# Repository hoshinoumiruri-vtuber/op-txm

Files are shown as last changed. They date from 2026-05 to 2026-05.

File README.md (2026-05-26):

# op-txm — Transformer-Output Condenser Microphone

Solid-state condenser microphone with transformer-balanced output.

---

## Table of Contents

1. [System Architecture](#1-system-architecture)
2. [Technical Specifications](#2-technical-specifications)
3. [Output Transformer — Neutrik NTE10/3](#3-output-transformer--neutrik-nte103)
4. [Engineering Verification and Simulation Results](#4-engineering-verification-and-simulation-results)
5. [Toolchain](#5-toolchain)
6. [Getting Started](#6-getting-started)
7. [Project Phases](#7-project-phases)
8. [Repository Structure](#8-repository-structure)

---

## 1. System Architecture

```
[XLR Phantom 48V] --> [LR8 Pre-reg 35.2V + Charge Pump] --> [JFET Input Buffer + DC Servo]
                              |                                            |
                        [TPS7A3901 +/-15V]                   [K47/K87 De-emphasis EQ]
                                                                           |
                                                          [NTE10/3 Output Transformer 1:3]
                                                                           |
                                                                    [XLR Balanced Out]
```

| Stage | Description |
|---|---|
| Power | LR8 pre-regulator (48V phantom → 35.2V). Diode charge pump → V_BOOST for JFET drain. TPS7A3901 WSON-12 → ±15V op-amp supply. Total draw 9.1 mA typ (< 10 mA IEC 61938). |
| Input | High-Z JFET buffer (MMBF170LT1G SOT-23) with op-amp DC servo for bias stability. |
| EQ | Active de-emphasis network tuned for K67/K87. Flat (K47) or −6 dB shelf above ~22 kHz (K87) via SJ1 solder bridge. |
| Output | Neutrik NTE10/3, reversed 3:1 connection (op-amp drives 3× winding, XLR from 1× winding): transformer-balanced, galvanic isolation, passive CMRR, Zout ≈ 255 Ω. |

---

## 2. Technical Specifications

| Parameter | Value |
|---|---|
| Supply | +48V phantom power (IEC 61938) |
| Internal rail | 35.2V (LR8 pre-reg) → ±15V (TPS7A3901); V_BOOST charge pump for JFET drain |
| Max current draw | < 10 mA (IEC 61938 phantom limit); typical 9.1 mA |
| Capsule | Takstar K87, 34 mm rim-terminated |
| Capsule compatibility | K47 (flat) and K87/K67 (de-emphasised) via SJ1 solder bridge |
| PCB form factor | 40×100 mm |
| Mounting | 4× M2.2 NPTH, rectangular pattern (30×80 mm) |
| Assembly | SMD for all active/passive components; through-hole for capsule leads and NTE10/3 transformer leads |
| De-emphasis network | R_shelf = 47 kΩ, C_deemph = 150 pF — −6 dB shelf above ~22 kHz |
| Output stage | Neutrik NTE10/3, reversed 3:1 connection (−9.5 dB, Zout ≈ 255 Ω) — standard Neumann/AKG practice |
| EQ op-amp | OPA1642AIDR (dual JFET-input, GBW=11 MHz, EIN=5.1 nV/√Hz) |
| Output balance | Transformer CMRR (passive) — no active output op-amp required |
| Output impedance | ~540 Ω referred to secondary (JFET 60Ω × n²=9) |

---

## 3. Output Transformer — Neutrik NTE10/3

### Confirmed specifications

| Parameter | Value | Source |
|---|---|---|
| Turns ratio | 1:3:10 (two secondary taps) | Neutrik datasheet |
| Selected tap | 1:3 (secondary = 1.8 kΩ) | Design choice |
| Primary impedance | 200 Ω | Neutrik / Farnell |
| Secondary impedance (1:3 tap) | 1.8 kΩ | Neutrik / Farnell |
| Secondary impedance (1:10 tap) | 20 kΩ | Neutrik / Farnell |
| Frequency response | 40 Hz – 20 kHz ±0.5 dB | Distributor spec |
| Solderability | IEC 68-2-20 compliant | Neutrik datasheet |
| Primary inductance | ~80 H (community measurement) | GroupDIY forum |
| Primary DCR (1× winding) | 105 Ω ±5% | Neutrik datasheet |
| Secondary DCR (3× winding) | 1.25 kΩ ±5% | Neutrik datasheet |
| Leakage inductance | **TBD — measure at bench** | — |

> After bench measurement, update DCR and leakage inductance values in `sim/tx_output.py` and `sim/signal_chain.py`.

### Wiring / connection — reversed 3:1 (Neumann/AKG standard)

Op-amp EQ output drives the **3× (secondary) winding**; XLR balanced output comes from the **1× (primary) winding**.

```
NTE10/3 lead colour (typical) — reversed 3:1 connection:
  3× winding (driven by EQ op-amp):
    Blue  → EQ op-amp output (hot drive)
    White → Signal GND (3× winding return)
    Yellow→ Centre tap → signal GND (if used; tie to GND or leave floating)
  1× winding (XLR balanced output):
    Red   → XLR pin 2 (hot)
    Black → XLR pin 3 (cold)
```

> **Verify lead colours against the physical unit** — Neutrik wire colours are not always consistent across production batches. Use an LCR meter to confirm winding connections before soldering.

### PCB mounting

The NTE10/3 is an encapsulated off-board transformer connected via its free wires. It is **not** mounted on the PCB directly.

- Solder the five leads to through-hole pads on the PCB (1.0 mm drill, 2.5 mm annular ring recommended)
- Secure the transformer body inside the mic capsule body with two cable ties through 2.5 mm NPTH slots at the PCB edge (or adhesive mount to the capsule basket)
- Allow enough wire slack for the transformer to not stress the PCB pads

---

## 4. Engineering Verification and Simulation Results

All simulations run analytically (Python) with ngspice batch mode for transient verification.

### 4.1 Power Stage

72V boost stage (Cockcroft-Walton charge pump), LR8 pre-regulator, TPS7A39 ±15V.

| Parameter | Value | Status |
|---|---|---|
| 72V rail ripple (after LC filter) | 0.088 µV p-p | PASS |
| LR8 junction temperature | 63.0 °C (45 °C ambient) | PASS |
| TPS7A39 junction temperature | 48.7 °C (45 °C ambient) | PASS |
| Phantom current draw | 9.09 mA typ / 10.97 mA max | PASS typ (< 10 mA IEC 61938) |

### 4.2 JFET Buffer + DC Servo

MMBF170 JFET, OPA2134 servo, Vdrain locked to 36 V ±1 V across 0–50 °C.

| Parameter | Value | Status |
|---|---|---|
| gm at operating point | 16.18 mA/V | — |
| Gain drift over temperature | 0.0 dB | PASS |
| Servo phase margin | 90° | PASS |
| EIN @ 1 kHz | 13.01 nV/√Hz | — |

### 4.3 K47/K87 De-emphasis EQ

| Frequency | K47 gain | K87 gain |
|---|---|---|
| 20 Hz | 0.00 dB | 0.00 dB |
| 1 kHz | 0.00 dB | −0.03 dB |
| 10 kHz | 0.00 dB | −1.74 dB |
| 20 kHz | 0.00 dB | −3.65 dB |

Phase margin ≥ 90° across all EQ states.

### 4.4 Full Signal Chain (sim/signal_chain.py) — ngspice PASS

K47/K87 modes, JFET → OPA1642 EQ → NTE10/3 → 600 Ω balanced load.

| Parameter | Value | Notes |
|---|---|---|
| Differential gain @ 1 kHz (K47) | +16.0 dB | Balanced output, reversed 3:1 TX |
| Differential gain @ 20 kHz (K47) | +16.0 dB | Flat within 0.1 dB |
| K87 shelf @ 20 kHz | −3.7 dB | Expected — shelf corner is 22.6 kHz |
| K87 shelf @ 100 kHz | −5.9 dB | PASS (target −6 dB ±1.5 dB) |
| Bandwidth LF −3 dB (K47) | 10.2 Hz | Sub-Hz with servo-locked Q-point |
| Bandwidth HF −3 dB (K47) | > 100 kHz | Well above audio band |
| Phase @ 1 kHz (K47) | +0.5° | — |
| Transformer connection | Reversed 3:1 (−9.5 dB) | Op-amp drives 3× winding; Zout ≈ 255 Ω at XLR |
| Transformer LF −3 dB | ~0.30 Hz | Estimated (Ldriven=720 H, DCR_sec=1.25 kΩ) |
| Transformer HF −3 dB | ~415 kHz analytical | Estimated (Lleak TBD at bench); reversed 3:1 extends HF vs forward |

> Transformer DCR and leakage inductance are estimated. Update `sim/tx_output.py` and `sim/signal_chain.py` after bench measurement.

---

## 5. Toolchain

| Tool | Purpose | Version |
|---|---|---|
| Python | Primary language | 3.12+ |
| uv | Package and environment management | 0.11.8+ |
| ngspice | SPICE simulation engine | 46 |
| PySpice | Python wrapper for ngspice | 1.5 |
| KiCad | PCB design (code-driven layout via kiutils) | 10.0.3+ |
| numpy / scipy | Numerical analysis | 2.4 / 1.17 |
| matplotlib | Plotting | 3.10 |

> **PCB layout is code-driven** — kiutils scripts generate the KiCad PCB file. See `docs/pcb_routing_knowhow.md` for routing rules and constraints.

> **ngspice -b batch mode** — do not use PySpice's `NgSpiceShared` API (unreliable with ngspice 42+).

---

## 6. Getting Started

### Prerequisites

```bash
# Arch Linux
sudo pacman -S ngspice kicad

# Ubuntu / Debian
sudo apt install ngspice kicad
```

### Python Environment

```bash
uv sync
```

### Running Simulations

```bash
source .venv/bin/activate

# Power stage
python sim/boost_72v.py

# JFET buffer + DC servo
python sim/dc_servo.py

# K47/K87 de-emphasis EQ
python sim/dual_capsule_eq.py

# Transformer output stage (update DCR/Lleak values first)
python sim/tx_output.py

# Generate all plots
python sim/generate_plots.py
```

### Generating PCB Files

The KiCad project is fully code-driven. Two scripts must be run before opening KiCad:

```bash
# 1. Generate the KiCad project file (net classes, DRC rules, HV net assignments)
python pcb/project.py        # → pcb/op-txm.kicad_pro

# 2. Generate the board layout (outline, component placement, GND fill zone)
python pcb/layout.py         # → pcb/op-txm.kicad_pcb + pcb/op_txm_layout.png
```

Open the project in KiCad 10:

```bash
kicad pcb/op-txm.kicad_pro
```

> Always open via `.kicad_pro`, not `.kicad_pcb` directly — the project file carries the HV net class assignments and DRC rules. If you regenerate either file, re-open the project in KiCad (the board file is reloaded automatically).

After opening in KiCad:
1. **Fill All Zones** (`B` key) — floods the B.Cu GND plane
2. **Run DRC** — verify zero clearance violations, zero unrouted nets flagged as errors
3. **Route remaining nets** interactively (capsule signal, HV supply, EQ → transformer)
4. **Export Gerbers** — `File → Fabrication Outputs → Gerbers`, output to `gerbers/`

---

## 7. Project Phases

### Phase 1: Simulation — COMPLETE

- [x] Power stage simulation (boost_72v.py) — 0.088 µV ripple PASS
- [x] Phantom power budget (phantom_budget.py) — 9.09 mA typ PASS (< 10 mA IEC 61938)
- [x] JFET buffer + DC servo simulation (dc_servo.py)
- [x] K47/K87 EQ simulation (dual_capsule_eq.py)
- [x] Transformer output stage analytical model (tx_output.py) — LF=0.30 Hz, HF=415 kHz
- [x] Full signal-chain AC sweep (signal_chain.py) — 16.0 dB diff gain, K87 shelf −5.9 dB @ 100 kHz PASS
- [ ] Measure NTE10/3 DCR and leakage inductance (bench LCR meter) — deferred to Phase 4
- [ ] Update tx_output.py and signal_chain.py with measured values — deferred to Phase 4

### Phase 2: PCB Layout (code-driven via kiutils) — IN PROGRESS

- [x] Add kiutils to pyproject.toml, scaffold pcb/layout.py
- [x] Generate .kicad_pro (pcb/project.py) with HV net class and DRC rules
- [x] Define board outline: 35×85 mm, 4× M2.2 NPTH (30×80 mm pattern) — pcb/outline.py
- [x] Place components via script: power stage, JFET buffer, EQ, transformer TH pads
- [x] Define HV keepout zone (outline.py), B.Cu GND plane (layout.py)
- [x] Add NPTH zip-tie slots (2.5 mm) at PCB edge for transformer retention
- [x] Transformer bobbin cutout (10×8 mm interior rectangle, Edge.Cuts)
- [ ] Route critical nets (capsule signal, HV supply, EQ output) — interactive in KiCad
- [ ] DRC — zero clearance violations
- [ ] Fill All Zones, export Gerbers

### Phase 3: BOM + Procurement

- [x] Generate BOM (bom/generate_bom.py) — 31 line items, 35 SMD placements
- [x] DFM review (bom/txm_bom_dfm.txt) — board parameters, TH hand-solder notes
- [ ] Order NTE10/3 (check stock: Farnell, Mouser)
- [ ] Order long-lead parts: IXYS LR8, TPS7A3901

### Phase 4: Bench Validation (hardware)

- [ ] Power-on: verify 35.2V LR8 rail, ±15V, V_BOOST
- [ ] DC servo: check Vdrain = 36V ±1V across 0–50°C
- [ ] Noise floor A-weighted (target < 14 dB-A)
- [ ] Frequency response 20Hz–20kHz (±1 dB)
- [ ] Output CMRR via transformer (target > 60 dB at 1 kHz)
- [ ] Phantom current draw (target < 7 mA)
- [ ] Acoustic evaluation

---

## 8. Repository Structure

```
op-txm/
├── pyproject.toml
├── README.md
├── sim/
│   ├── boost_72v.py          # Power stage simulation
│   ├── dc_servo.py           # JFET DC servo simulation
│   ├── dual_capsule_eq.py    # K47/K87 EQ simulation
│   ├── tx_output.py          # NTE10/3 transformer output stage
│   ├── generate_plots.py     # Batch plot generator
│   └── models/               # Ngspice device models
├── bom/
│   └── generate_bom.py       # BOM generator
├── pcb/                      # KiCad project files (code-driven layout)
│   └── notes.md              # PCB constraints and layout notes
├── docs/
│   └── pcb_routing_knowhow.md # Routing rules and constraints
└── assets/
    └── sim_results/           # Generated plots
```

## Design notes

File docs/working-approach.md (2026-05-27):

# Working Approach — op-txm PCB Development

## Core rule

**Write code → run → fix errors → commit. No pre-solving geometry in prose.**  
If the geometry is unclear, write the attempt, see what DRC says, iterate.

---

## Iteration loop

```
edit layout.py
→ uv run python pcb/layout.py
→ open in KiCad → Inspect → Design Rules Checker → save report to pcb/DRC.rpt
→ read DRC.rpt, pick next root-cause short
→ repeat
```

DRC.rpt is gitignored (generated artefact). The .kicad_pcb is also gitignored — it is always regenerated from layout.py.

---

## Batching

Fix **one root-cause short per commit**. A root-cause short typically clears 5–20 downstream
solder_mask_bridge / tracks_crossing entries. Do not attempt multiple root causes in one pass —
the interactions are hard to predict and error output becomes unreadable.

After each fix commit, re-run DRC and update `docs/drc-fix-plan.md` with new violation count.

---

## DRC priority order

1. **shorting_items** — hard shorts between different nets (circuit-breaking)
2. **tracks_crossing / clearance** — routing overlaps, HV clearance violations
3. **unconnected_items** — floating pads
4. **Warnings** (text_height, silk_overlap, lib_footprint, via_dangling) — fix last or waive

**Always waive**: WSON-12 (U3 TPS7A3901) adjacent-pad clearances — structural, 0.5mm pitch.

---

## Routing conventions

| Net type | Width | Layer |
|---|---|---|
| PHANTOM, V_BOOST, BP_CAPSULE | 0.40 mm | F.Cu |
| P15V, N15V, P48V_LDO, GND | 0.30 mm | F.Cu |
| SIG_EQ, SRV_OUT, SRV_INT, VSOURCE | 0.20 mm | F.Cu |
| VGATE, FP_CAPSULE | 0.15 mm | F.Cu |
| Via | Ø0.60 mm / drill 0.30 mm | F.Cu–B.Cu |

HV net (PHANTOM, V_BOOST, BP_CAPSULE) clearance: **0.5 mm** to any other net (enforced via op-txm.kicad_dru).

---

## Pad position reference (absolute canvas coords)

All components are placed relative to board centre (100, 100).

### U1 OPA1642 SOIC-8 at (100, 81), pitch 1.27 mm
Left pads X=97.3: pin1=SIG_EQ(79.095), pin2=SIG_EQ(80.365), pin3=GND(81.635), pin4=N15V(82.905)  
Right pads X=102.7: pin5=GND(82.905), pin6=SRV_INT(81.635), pin7=SRV_OUT(80.365), pin8=P15V(79.095)  
Pad half-width = 0.775 mm → right-pad right edge = **103.475 mm** (safe-zone boundary for P15V trunk)

### U3 TPS7A3901 WSON-12 at (100, 110), pitch 0.5 mm
Left pads X=98.35: p1=P48V_LDO(108.75), p2=P48V_LDO(109.25), p3=TPS_FB_NEG(109.75), p4=N15V(110.25), p5=TPS_FB_NEG(110.75), p6=P48V_LDO(111.25)  
Right pads X=101.65: p7=P48V_LDO(111.25), p8=TPS_FB_POS(110.75), p9=P15V(110.25), p10=TPS_FB_POS(109.75), p11=P48V_LDO(109.25), p12=P48V_LDO(108.75)  
EP (GND) centre (100, 110), 1.7×1.7 mm

### U2 LR8 SOT-89 at (91, 110.5)
pin1=LR8_ADJ(89.5, 112.5), pin2=P48V_LDO(91.0, 112.5), pin3=PHANTOM(92.5, 112.5), tab=PHANTOM(91.0, 108.5)

---

## DRC fix batches (see drc-fix-plan.md for detail)

| Batch | Root cause | Status |
|---|---|---|
| B1 | V_BOOST trunk: F.Cu jog → via at (108.5,63.7) → B.Cu X=113.1 → via at (113.1,116) → F.Cu | DONE — 273→263 |
| B2 | Move P15V trunk X=103.5 → X=104.5 (clears U1 right pads + N15V) | TODO |
| B3 | Reroute N15V around P48V_LDO stubs (not through Y=108.5) | TODO |
| B4 | Jog PHANTOM trunk west of LR8_ADJ pad at (89.5, 112.5) | TODO |
| B5 | Reroute P48V_LDO from U2 around SIG_EQ trunk at X=93.5 | TODO |
| B6 | Fix XLR_COLD jog X=110.7 → X=110.3 (clears XLR2 HOT pad) | TODO |
| B7 | Move GND via (88,121) — SIG_EQ trunk endpoint; fix SIG_EQ→TX_DRV_HOT net | TODO |
| B8 | Connect TPS_FB_POS/NEG to U3 pins 8,10 and 3,5 | TODO |
| B9 | Connect GND islands (decoupling cap GND pads → stitching vias) | TODO |

---

## File map

```
pcb/
  layout.py          — all component placement + routing (edit this)
  outline.py         — board outline, mounting holes, TX cutout (rarely edit)
  op-txm.kicad_dru   — custom HV clearance rules
  op-txm.kicad_pcb   — generated (gitignored, regenerate with layout.py)
  DRC.rpt            — generated (gitignored, save from KiCad DRC dialog)

docs/
  drc-fix-plan.md    — root-cause analysis + batch fix plan
  working-approach.md — this file
  pcb_routing_knowhow.md — general routing rules (ported from OCM)
```

---

## Git commit hygiene

- One commit per completed batch
- Commit message format: `pcb: fix <short description> (DRC Bn)`
- Never commit .kicad_pcb or DRC.rpt (gitignored)
- After all DRC errors resolved → final commit: `pcb: DRC clean, ready for Gerber export`

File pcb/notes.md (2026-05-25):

# PCB Design Notes — op-txm

## Board outline (same as OCM body)

- Size: 40×100 mm
- Mounting: 4× M2.2 NPTH at corners of 30×80 mm rectangular pattern
- Form factor: cylindrical microphone body, same as OCM

## Pad rules

- **SMD pads only** for resistors, capacitors, ICs, diodes — standard reflow assembly
- **Through-hole** for:
  - Capsule backplate and diaphragm leads (2 holes)
  - NTE10/3 transformer leads (5 holes — primary ×2, secondary ×3 or per winding count)
  - XLR wire solder points (3 holes — pin 1/2/3)

## Through-hole specifications

| Connection | Drill | Annular ring | Notes |
|---|---|---|---|
| Capsule leads | 0.8 mm | 1.5 mm | Fine wire; keep away from HV copper |
| Transformer leads (NTE10/3) | 1.0 mm | 2.5 mm | Hand-solder after reflow |
| XLR cable wires | 1.0 mm | 2.0 mm | At PCB tail end |

## HV keepout zone

- PHANTOM (48V) and V_BOOST (72V) nets require 0.5 mm clearance to all other copper
- Define a KiCad keepout zone in the bottom ~30 mm of the board (power zone)
- Capsule bias net (BP_CAPSULE, ~48V) — keep isolated from signal traces; minimum 0.5 mm clearance

## NTE10/3 transformer lead pads

The NTE10/3 has **5 free-wire leads** in the 1:3 configuration (2 primary + 2 for 1:3 secondary tap + 1 centre tap).
All leads get through-hole pads. Connection is **reversed 3:1** — op-amp drives the 3× secondary, XLR from 1× primary.

| Pad label | Drill | Function |
|---|---|---|
| TX_S3_HOT, TX_S3_RTN | 1.0 mm | 3× secondary — **driven by op-amp EQ output** (Blue / White leads) |
| TX_S3_CT | 1.0 mm | 3× secondary centre tap → signal GND (Yellow lead, tie to GND) |
| TX_P1, TX_P2 | 1.0 mm | 1× primary — **XLR pin 2 (hot) and XLR pin 3 (cold)** (Red / Black leads) |

The 1:10 secondary dummy pads serve two purposes:
1. Mechanical anchor — the leads are still soldered for strain relief
2. Future option — can be used if a different gain structure is needed

Mark the dummy pads in silkscreen: "TX 1:10 — NC" (no connect).
Do NOT leave 1:10 secondary leads hanging in air — solder them to the dummy pads.

Add 2× NPTH slots (2.5 mm) at PCB edge for cable-tie retention of the transformer body.

## NTE10/3 mounting

- Transformer body sits **off the PCB** — inside the mic basket or body, secured with cable ties
- Two 2.5 mm NPTH slots at PCB edge (or holes at 15 mm spacing) for cable tie retention
- Lead wire length: allow 40–60 mm of free wire from transformer body to PCB solder pads
- Solder pads for transformer leads: through-hole, 1.0 mm drill, placed near the PCB tail (XLR end)

## Capsule connection

- Two through-holes for capsule leads (backplate and diaphragm)
- Place at the PCB head (capsule end, opposite XLR)
- Keep VGATE trace (hi-Z, 1 GΩ gate bias) away from all other copper — 0.5 mm isolation clearance
- VGATE trace width: 0.15 mm, no copper pour closer than 0.5 mm on either layer

## Signal chain reference (left to right on 100 mm axis)

```
[Capsule TH pads] -- [JFET + Servo zone] -- [EQ zone] -- [Power zone] -- [Transformer TH pads + XLR TH pads]
   Y=0 (head end)                                                              Y=100 mm (tail end)
```

## Ground plane

- Solid B.Cu GND fill, 0.3 mm clearance, 0.5 mm thermal relief on SMD pads
- GND stitching: ≥1 via per zone, Ø0.3 mm drill / 0.6 mm Cu
- TPS7A39 exposed pad: 4 thermal vias (2×2, Ø0.25 mm) under EP

## Trace widths

| Net | Width |
|---|---|
| PHANTOM, V_BOOST (HV) | 0.40 mm |
| Power rails (P15V, N15V, P48V_LDO) | 0.30 mm |
| Signal | 0.15–0.20 mm |
| VGATE, FP_CAPSULE (hi-Z) | 0.15 mm |

## Fiducials

3× fiducials (FID1/2/3) at board corners, 1 mm Cu dot, 3 mm exclusion zone.

## See also

- `docs/pcb_routing_knowhow.md` — detailed routing rules and lessons from OCM code-driven layout

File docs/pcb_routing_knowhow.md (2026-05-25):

# PCB Routing Know-How (ported from OCM)

Accumulated routing rules and lessons from the OCM code-driven layout sessions.
Apply these when laying out op-txm manually in KiCad.

---

## Trace widths

| Net type | Width |
|---|---|
| V_BOOST, PHANTOM, BP_CAPSULE (HV) | 0.40 mm |
| Power rails (P15V, N15V, P48V_LDO, etc.) | 0.30 mm |
| Signal | 0.15–0.20 mm |
| VGATE, FP_CAPSULE (hi-Z capsule gate) | 0.15 mm |

HV traces (PHANTOM, V_BOOST) need 0.5 mm clearance to any lower-voltage net.

---

## Component packages (pad geometry reference)

| Package | Pad offset from center |
|---|---|
| 0402 | ±0.575 mm along long axis |
| 0805 | ±1.1 mm along long axis |
| SOIC-8 | X = ±2.7 mm, Y = ±0.635 / ±1.905 mm (1.27 mm pitch, 4 per side) |
| SOD-323 | ±1.05 mm along long axis |
| WSON-12 (TPS7A39) | Very tight pin pitch — expect DRC clearance warnings from adjacent HV traces |

---

## High-voltage keepout

Define a KiCad keepout zone around all PHANTOM / V_BOOST copper.
Minimum 0.5 mm clearance to any other copper.
On the 40×100 mm form factor, power zone occupies the bottom ~30 mm of the board.

---

## Ground plane strategy

- Solid B.Cu GND fill, 0.3 mm clearance, 0.5 mm thermal relief spokes on SMD pads
- GND stitching vias: at least one via per major copper island, Ø0.3 mm drill / 0.6 mm Cu
- Place stitching vias near decoupling caps and near the JFET source/gate area
- TPS7A39 exposed pad: minimum 4 thermal vias (2×2 grid, Ø0.25 mm drill) under the EP

---

## Routing topology lessons

### Crossing avoidance
- Route power trunks first (PHANTOM → LR8 → V_BOOST → regulator); signal routes come last
- Use 45° bends everywhere; avoid 90° corners
- If a straight route would cross another net, try: (a) a B.Cu via pair, (b) a waypoint detour around the obstacle, (c) route on B.Cu if the signal is not HV

### Structural overlap situations to accept
The following overlap types are geometrically unavoidable on tightly packed 40×100 mm boards and can be accepted after DRC review:
- Two adjacent IC pins exiting the same column (SOIC-8 pins 6/7 or 1/2)
- Power routes along the Y=130 corridor near SOD-323 diodes + inductor
- TPS7A39 WSON-12 adjacent-pin routes (D-cluster)

### Key learned rules
1. **Don't move a component to fix one overlap if it creates a crossing** — crossings are harder to resolve than overlaps.
2. **Always check both layers** after any component move; B.Cu routes cascade unexpectedly.
3. **Same-net B.Cu routes can self-cross** — check same-net pairs in the crossing audit too.
4. **SOIC-8 pin-column constraint**: pins 1/2 and 6/7 share the same X column; routes from these pin pairs will always overlap at the IC body edge. Accept as structural after confirming no inter-net DRC violation exists.
5. **HV corridor at Y=130** (power zone bottom): if D2 (SOD-323) and L1 (inductor) share Y=130, both V_BOOST and P48V_LDO are forced into that channel. No fix without relocating both; accept and note in DRC report.

---

## Fiducials

Place 3 fiducials (FID1/2/3) at board corners for PCBA pick-and-place alignment.
Keep 3 mm exclusion zone around each fiducial.

---

## PCB form factor (inherited from OCM)

- Board: 40×100 mm
- Mounting: 4× M2.2 NPTH, rectangular pattern 30×80 mm
- Assembly: 100% SMD except the NTE10/3 transformer (through-hole leads, off-board)
- Transformer mounting: zip tie slots or holes at board edge; transformer body sits outside PCB or in a cut-out

---

## Transformer (NTE10/3) PCB footprint notes

- NTE10/3 is an encapsulated audio transformer — leads exit the bottom
- Drill lead holes to fit lead diameter (check datasheet); use 1.0 mm drill as starting point
- Add two 2.5 mm NPTH slots or holes ~15 mm apart for zip tie retention
- Copper pads for transformer leads should be through-hole, minimum 2.5 mm annular ring (hand-soldering clearance)
- No SMD alternative — this part must be wave-soldered or hand-soldered last, after reflow

---

## Through-hole rules (capsule and transformer)

**Rule: only use SMD copper pads for SMD components. Capsule leads and transformer leads use through-hole (TH) drill holes.**

| Connection | Drill | Annular ring | Why |
|---|---|---|---|
| Capsule leads (2 holes) | 0.8 mm | 1.5 mm | Fine wire; solder after reflow |
| NTE10/3 transformer leads (5 holes) | 1.0 mm | 2.5 mm | Thicker lead wire; hand-solder last |
| XLR cable wires (3 holes) | 1.0 mm | 2.0 mm | At PCB tail end |
| Cable-tie NPTH slots for TX1 | 2.5 mm NPTH | no copper | Mechanical retention only |

- Do **not** use SMD pads for capsule or transformer connections
- Through-hole pads can be wave-soldered or hand-soldered after PCBA reflow
- Keep capsule TH pads at the head end (Y≈0), transformer TH pads at the tail end (Y≈100 mm)
- Capsule VGATE hole: isolate from all copper by 0.5 mm minimum on both layers

## DFM checklist (Taiwan PCBA)

- [ ] All SMD pads: minimum 0.15 mm solder mask expansion
- [ ] All SMD pads: minimum 0.15 mm silkscreen clearance
- [ ] Fiducials: 3 minimum, 1 mm copper dot + 3 mm clearance
- [ ] Minimum drill: 0.2 mm (laser via) or 0.3 mm (mechanical)
- [ ] Minimum track/space: 0.1 mm / 0.1 mm (prefer 0.15 mm / 0.15 mm for yield)
- [ ] No silkscreen over pads
- [ ] Paste layer: avoid paste on large exposed pads without thermal relief

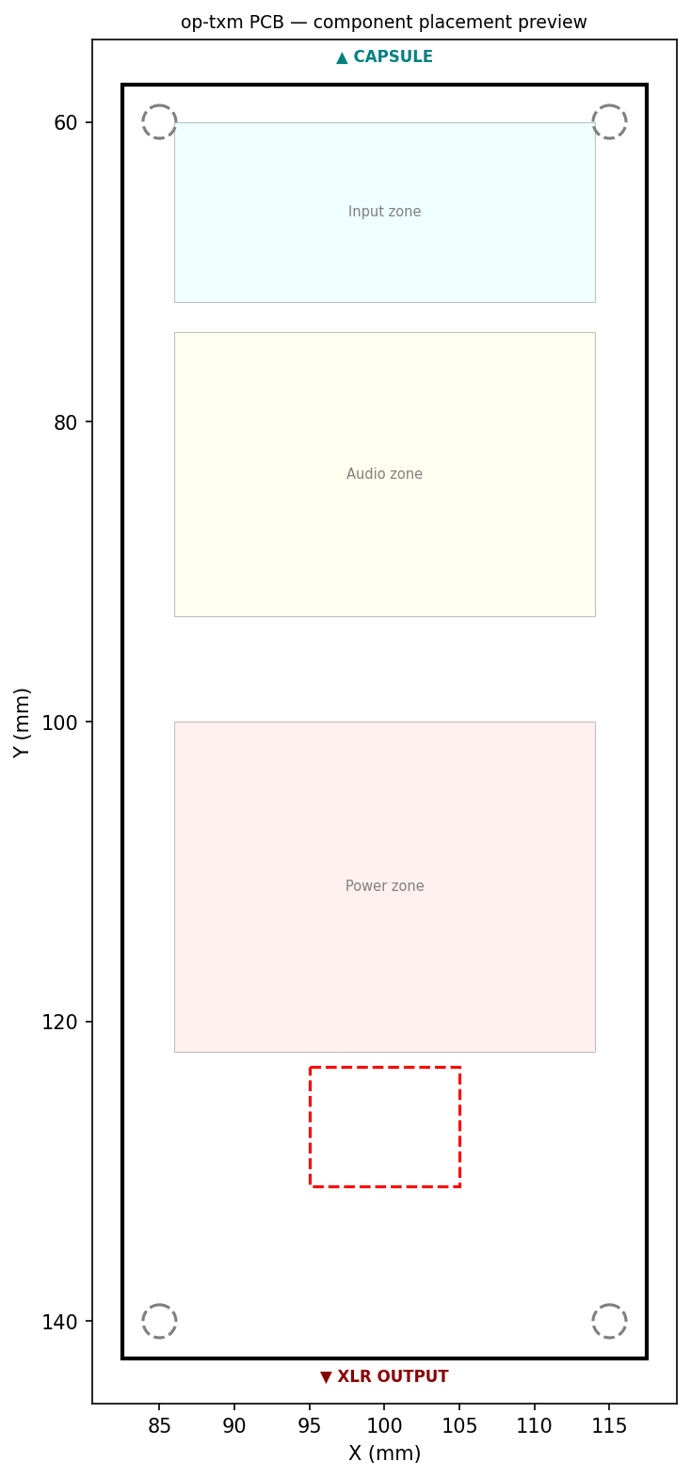
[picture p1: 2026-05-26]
pcb/op_txm_layout.png

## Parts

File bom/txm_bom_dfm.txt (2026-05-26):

op-txm — DFM Review
================================================================

  Total BOM line items : 32
  SMD placements       : 36
  Off-board (hand TH)  : 1
  DNP                  : 0

PCB / DFM parameters
----------------------------------------------------------------
  Board size                       35 × 85 mm, 2-layer FR4 1.6 mm
  Mounting holes                   4× M2.2 NPTH, 30 × 80 mm pattern
  Min drill (mechanical)           0.8 mm (capsule pads), 1.0 mm (TX/XLR TH)
  Min track / space                0.15/0.15 mm signal; 0.40/0.50 mm HV
  Solder mask expansion            0.05 mm all SMD pads
  Silkscreen clearance             0.12 mm from pads
  Fiducials                        3× FID (F.Cu copper dot, 1 mm dia, 3 mm CY)
  HV clearance                     0.5 mm Cu-to-Cu on PHANTOM/V_BOOST/BP_CAPSULE nets
  HV copper-edge clearance         0.5 mm (IPC-2221 for 48–72 V)
  TPS7A39 WSON-12 EP               Exposed pad to B.Cu GND plane via thermal vias
  B.Cu GND plane                   Full-board pour, 1 mm pullback from Edge.Cuts
  Post-reflow TH                   NTE10/3 leads hand-soldered (5 pads); XLR wires (3 pads)
  Capsule leads                    3× TH pad, 0.8 mm drill, 1.5 mm ring
  NPTH cable-tie slots             2× 2.5 mm NPTH (SLOT1, SLOT2) for transformer retention

Off-board / hand-soldered parts
----------------------------------------------------------------
  TX1        NTE10/3              Long-lead. Hand-solder 5 leads to TH pads TX_S3H/TX_S3R/TX_S

Long-lead parts — order first
----------------------------------------------------------------
  IXYS LR8K4-G        8–16 week lead time; check Mouser/Digi-Key
  Neutrik NTE10/3     check Farnell / Mouser stock
  TPS7A3901DSKR       check stock; WSON-12 may need stencil

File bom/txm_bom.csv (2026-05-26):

Refs | Qty | Value | Description | Package | Manufacturer | MPN | DNP | Notes
Q1 | 1 | MMBF170LT1G | N-JFET, Idss 2–6 mA, SOT-23, capsule buffer | SOT-23 | onsemi | MMBF170LT1G
R_D | 1 | 22k 1% | JFET drain load (VDRAIN → V_BOOST) | 0402 | Yageo | RC0402FR-0722KL
R_S | 1 | 1k 1% | JFET source degeneration | 0402 | Yageo | RC0402FR-071KL
D_RS | 1 | HSMS-2820 | Schottky clamp across R_S — anode=GND cathode=VSOURCE, protects JFET during transients | SOT-23 | Broadcom | HSMS-2820-TR1G
R_GBIAS | 1 | 10M 1% | Gate bias — 200 V rated 0805 required (VGATE = V_BOOST via R_GBIAS) | 0805 | Vishay | CRCW080510M0FKEA |  | HV net (VGATE ≈ 72 V). Must be 200 V rated.
C_IN | 1 | 10n 50V X7R | Input coupling cap FP_CAPSULE → VGATE | 0402 | Murata | GRM155R71H103KA88D
U1 | 1 | OPA1642AIDR | Dual JFET op-amp, SOIC-8, GBW=11 MHz, EIN=5.1 nV/√Hz | SOIC-8 | Texas Instruments | OPA1642AIDR |  | Section A = EQ inverting amp. Section B = DC servo integrator.
R_IN | 1 | 10k 1% | EQ input summing resistor (VSOURCE → IN-_A) | 0402 | Yageo | RC0402FR-0710KL
R_F | 1 | 47k 1% | EQ feedback resistor (OUT_A → IN-_A, K47 mode) | 0402 | Yageo | RC0402FR-0747KL
R_SHELF | 1 | 47k 1% | EQ shelf network series R (K87 de-emphasis) | 0402 | Yageo | RC0402FR-0747KL
C_DEEMPH | 1 | 150p C0G/NP0 | EQ de-emphasis shelf cap (−6 dB shelf above ~22 kHz for K87) | 0402 | Murata | GRM1555C1H151JA01D
SJ1 | 1 | SolderBridge 0Ω | K47/K87 mode select — open=K47 (flat), close=K87 (de-emphasis) | 0402 |  |  |  | Populate 0Ω for K87; leave open for K47.
R_INJ | 1 | 1M 1% | Servo gate injection R (SRV_OUT → VGATE low-pass) | 0402 | Yageo | RC0402FR-071ML
R_INT | 1 | 300k 1% | Servo integrator input R (VSOURCE → IN-_B) | 0402 | Yageo | RC0402FR-07300KL
C_INT | 1 | 10u 16V X5R | Servo integrator cap (sets servo f_c ≈ 0.05 Hz) | 0603 | TDK | C1608X5R1C106K080AC
C_P15_100n, C_N15_100n | 2 | 100n 25V X7R | ±15V HF bypass | 0402 | Murata | GRM155R71E104KA88D
C_P15_1u, C_N15_1u | 2 | 1u 25V X5R | ±15V bulk decoupling near U1 | 0603 | TDK | C1608X5R1E105K080AC
U2 | 1 | LR8K4-G | HV LDO, 48V PHANTOM → 34.3V (P48V_LDO), SOT-89 | SOT-89 | IXYS | LR8K4-G |  | Long-lead item — order early. Vout = 1.225×(1+270k/10k) = 34.3V.
R_LR8_1 | 1 | 270k 1% | LR8 Vadj divider high (P48V_LDO → LR8_ADJ) | 0402 | Yageo | RC0402FR-07270KL
R_LR8_2 | 1 | 10k 1% | LR8 Vadj divider low (LR8_ADJ → GND) | 0402 | Yageo | RC0402FR-0710KL
C_LR8_IN | 1 | 10u 100V X5R | LR8 input bypass (PHANTOM = 48V) | 0603 | TDK | C1608X5R2A106K080AC |  | 100 V rating required — PHANTOM net.
C_LR8_OUT | 1 | 4u7 50V X5R | LR8 output bypass (P48V_LDO = 34.3V) | 0603 | TDK | C1608X5R1H475K080AC
U3 | 1 | TPS7A3901DSKR | Dual LDO ±15V from 34.3V, WSON-12 3×3 mm | WSON-12 | Texas Instruments | TPS7A3901DSKR
R_TPS_P1, R_TPS_N1 | 2 | 127k 1% | TPS7A3901 output voltage set resistor (high side, +15V and −15V) | 0402 | Yageo | RC0402FR-07127KL |  | Vout+ = 1.188×(1+127k/10k) ≈ 16.3V — trim if exact ±15V required.
R_TPS_P2, R_TPS_N2 | 2 | 10k 1% | TPS7A3901 output voltage set resistor (low side) | 0402 | Yageo | RC0402FR-0710KL
C_P15_OUT, C_N15_OUT | 2 | 10u 25V X5R | TPS7A3901 output decoupling | 0603 | TDK | C1608X5R1E106K080AC
D1 | 1 | BAT54S | Dual Schottky SOT-23, 1-stage Cockcroft-Walton (PHANTOM → V_BOOST) | SOT-23 | Vishay | BAT54S-E3-08
C_PUMP | 1 | 100n 100V X7R | Charge pump capacitor | 0402 | Murata | GRM155R72A104KA88D |  | 100 V rating required — HV pump cap.
C_RSVR | 1 | 4u7 100V X5R | V_BOOST reservoir cap | 0603 | TDK | C1608X5R2A475K080AC |  | 100 V rating required.
L1 | 1 | 10mH 50mA | LC post-filter inductor (V_BOOST ripple suppression) | 0805 | Murata | LQH2MCN100K02L |  | Low-DCR ≤ 8Ω, Isat ≥ 50 mA.
C_LPF | 1 | 10u 100V X5R | LC post-filter output cap (V_BOOST → BP_CAPSULE) | 0603 | TDK | C1608X5R2A106K080AC |  | 100 V rating required.
TX1 | 1 | NTE10/3 | Audio output transformer 1:3:10, reversed 3:1 connection, free wires | Off-board | Neutrik | NTE10/3 |  | Long-lead. Hand-solder 5 leads to TH pads TX_S3H/TX_S3R/TX_S3C (3× secondary) + TX_P1/TX_P2 (1× primary) after reflow. Secure body with cable tie through SLOT1/SLOT2 NPTH holes.

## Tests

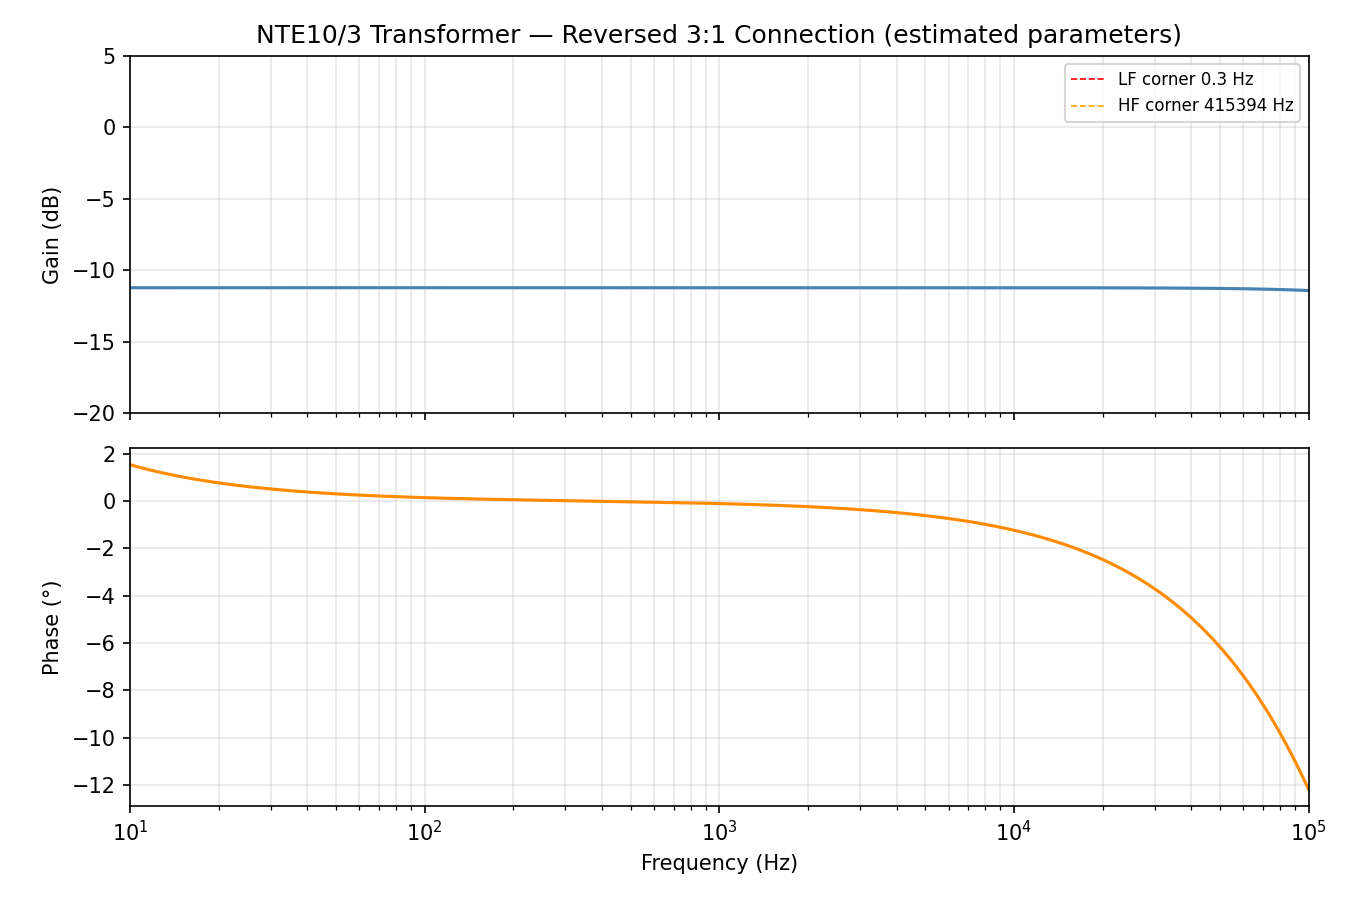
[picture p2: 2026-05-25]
assets/sim_results/tx_frequency_response.png

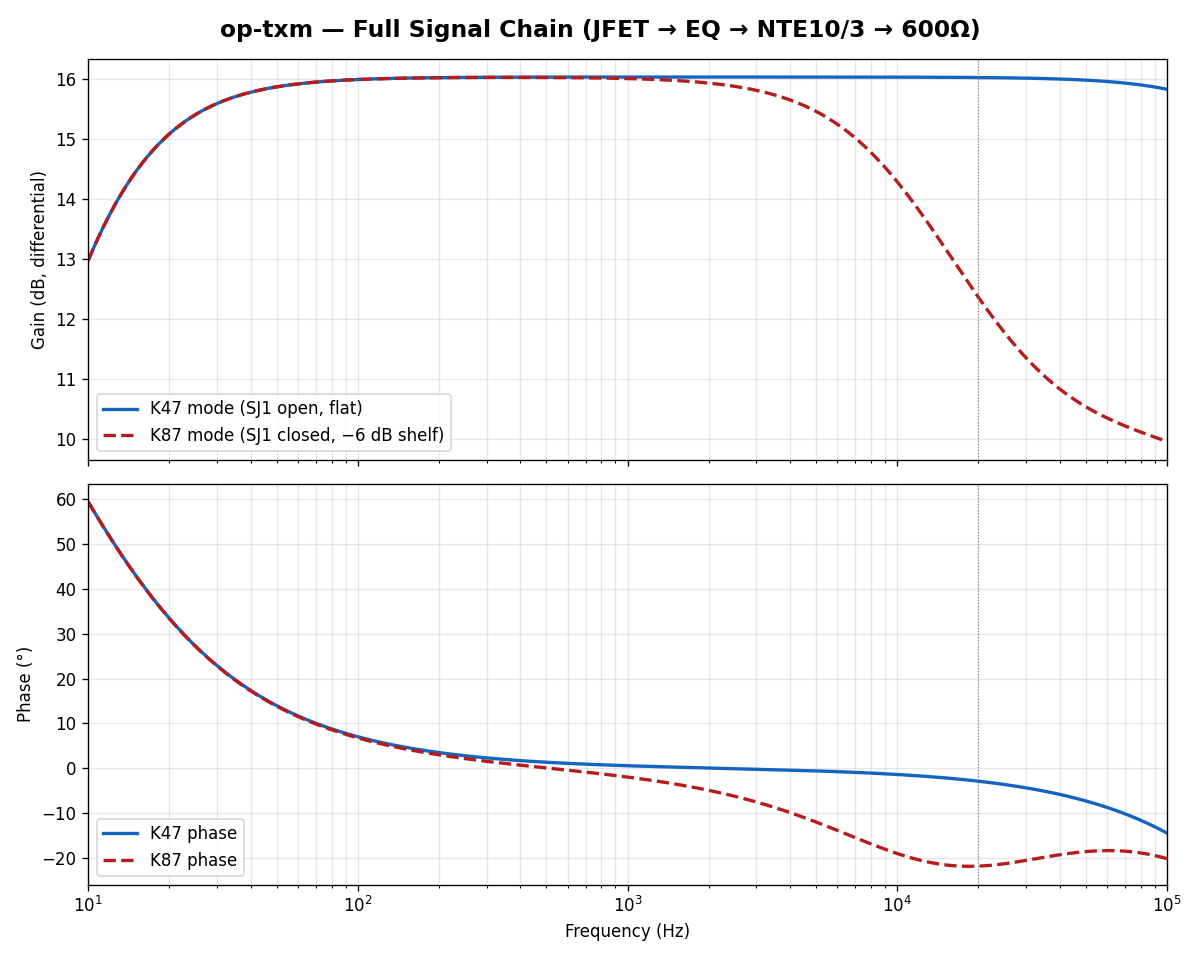
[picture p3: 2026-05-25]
assets/sim_results/signal_chain.png

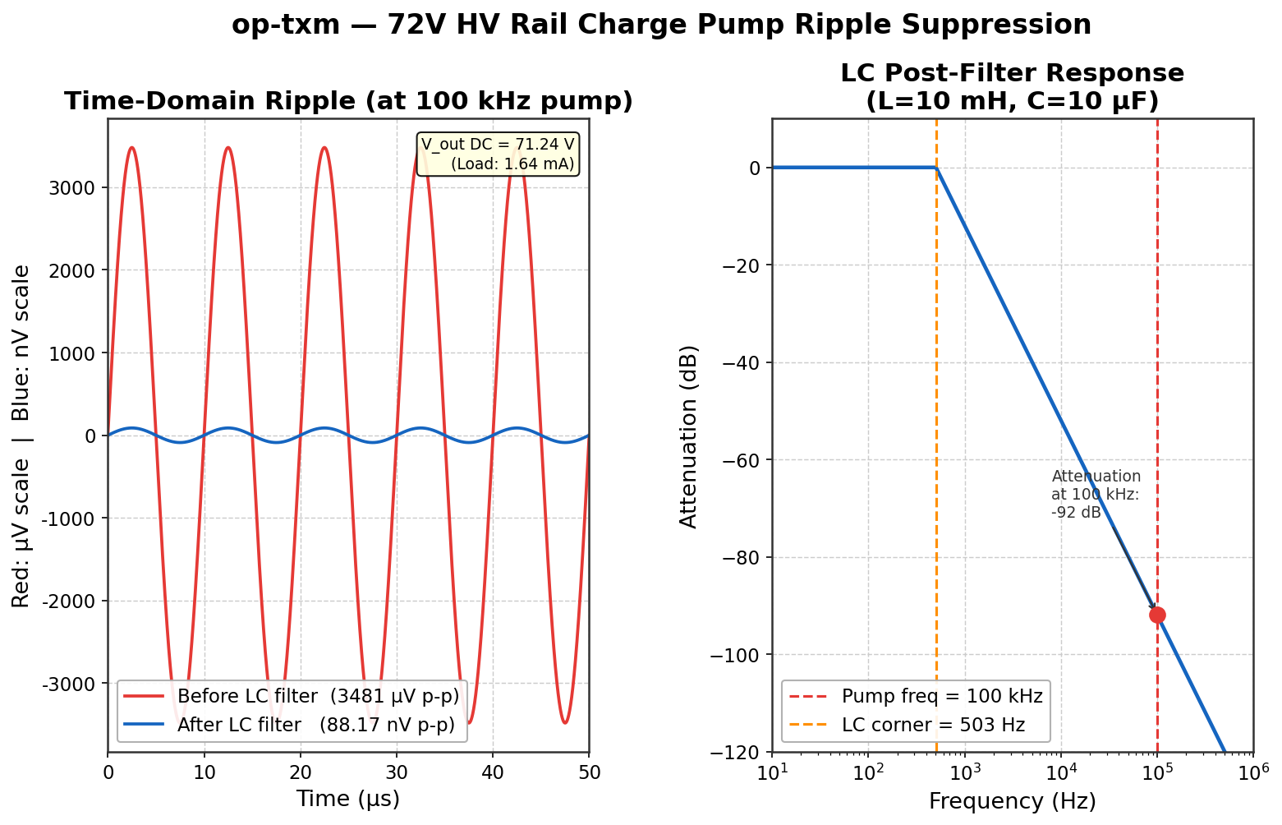
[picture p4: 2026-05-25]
assets/sim_results/hv_ripple_transient.png

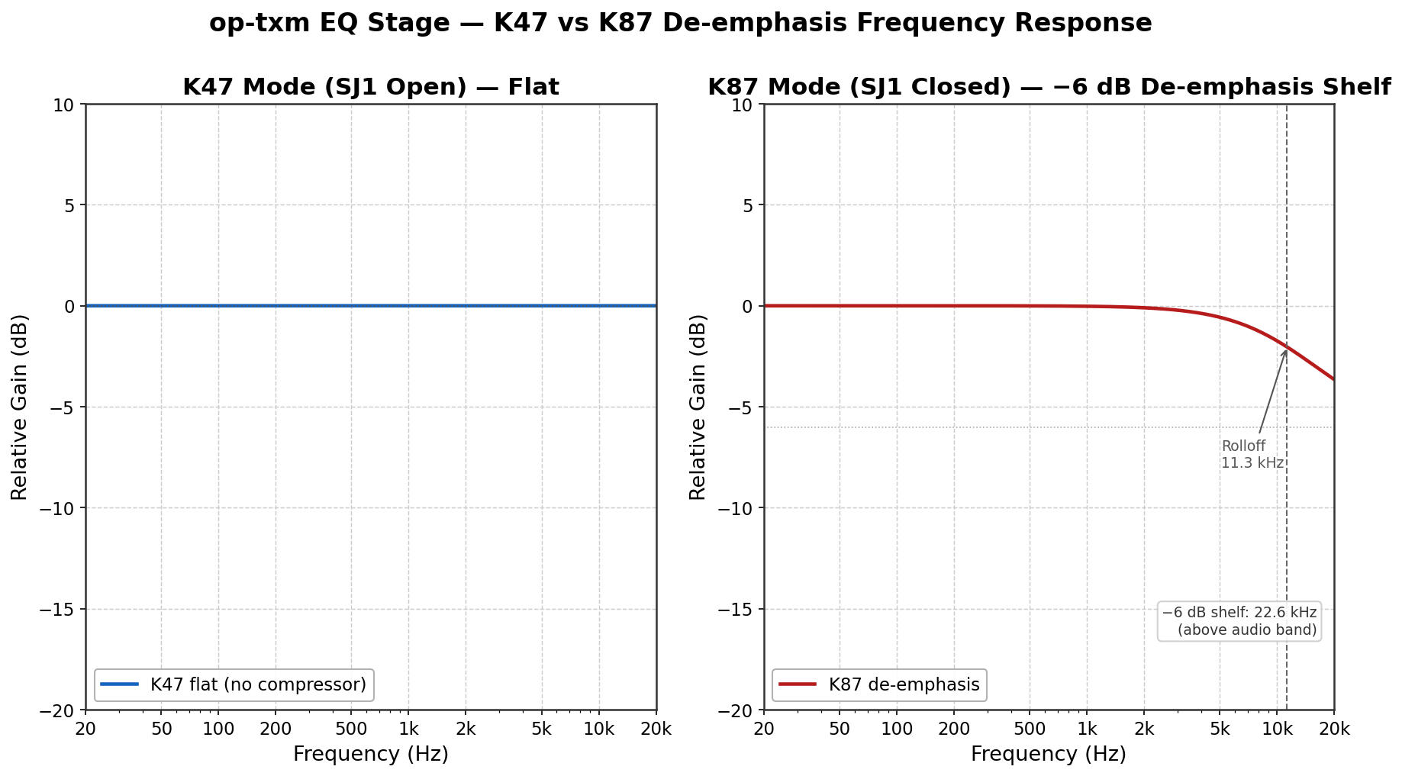
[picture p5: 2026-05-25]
assets/sim_results/eq_frequency_response.png

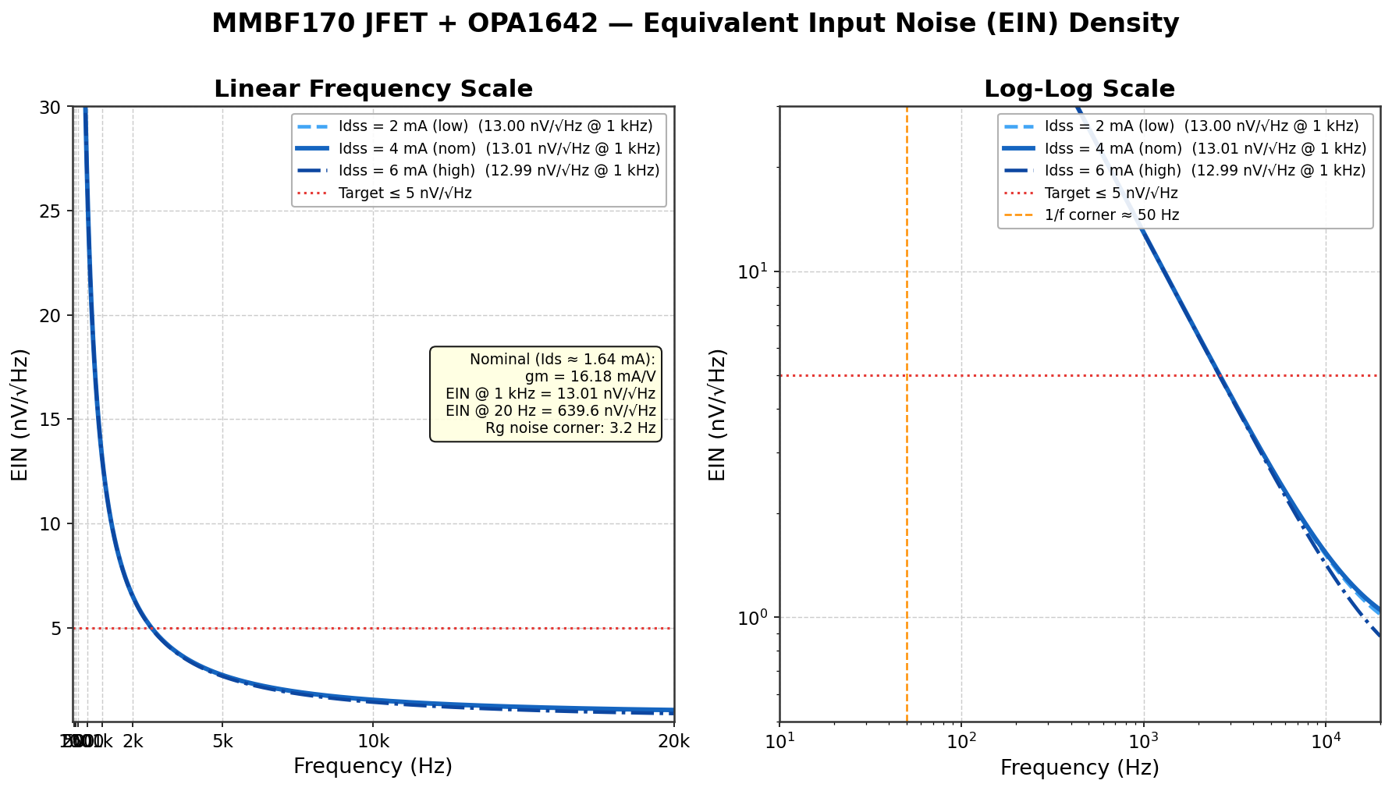
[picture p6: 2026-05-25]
assets/sim_results/jfet_noise_density.png

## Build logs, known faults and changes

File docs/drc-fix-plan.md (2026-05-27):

# DRC Fix Plan — op-txm

Generated: 2026-05-27. DRC round 2 had **273 violations** (pcb/DRC.rpt).

## Strategy (from research)

1. Fix **hard shorts** first — each short can cascade into 5–15 solder_mask_bridge + tracks_crossing entries
2. Fix **clearance violations** (V_BOOST/PHANTOM custom rules) next
3. Fix **unconnected pads** last (less board-breaking than shorts)
4. Ignore all **warnings** until errors are zero — text_height, lib_footprint, silk_overlap are cosmetic
5. WSON-12 (U3) adjacent-pad clearances are **structural** (0.5mm pitch vs 0.5mm clearance rule) — accept/waive

## Root-cause shorts (each one drives many errors)

### S1: P15V trunk (X=103.5) vs N15V trunk (X=103.425) — 0.075mm apart
- P15V: `_seg(103.5, 107.0, 103.5, 79.095, "P15V")` — runs Y=107 → 73
- N15V: `_seg(103.425, 108.5, 103.425, 110.0, "N15V")` — overlaps at X≈103.45
- Also: P15V at X=103.5 passes U1 right pads (pin5=GND at 102.7,82.905; pin6=SRV_INT at 102.7,81.635; pin7=SRV_OUT at 102.7,80.365) — pad half-width=0.775mm → pad right edge = 103.475mm → P15V at 103.5 is only 0.025mm clear → DRC short
- **Fix**: Move P15V trunk east to X=104.5 (safe margin from U1 pads and N15V)

### S2: N15V horizontal at Y=108.5 crosses P48V_LDO stubs at Y=108.75
- N15V runs X=96.5→103.425 at Y=108.5 (W=0.3mm → top edge at Y=108.35)
- P48V_LDO stubs: left at (98.35,108.75) pad half-h=0.125 → bottom edge 108.625 — gap only 0.275mm
- Also shorts: P48V_LDO east trunk at X=102.5 runs Y=105→112 — N15V at Y=108.5 crosses it
- **Fix**: Route N15V below Y=112 (south of P48V_LDO east trunk end at Y=112), then approach R_TPS_N1 from below

### S3: P48V_LDO horizontal at Y=105 crosses SIG_EQ trunk at X=93.5
- P48V_LDO: `_seg(94.95, 105.0, 102.5, 105.0)` — passes X=93.5 where SIG_EQ trunk runs Y=87.5→121
- Wait: seg starts at X=94.95, so it starts right of X=93.5 — crossing happens because SIG_EQ vertical passes at X=93.5 while P48V_LDO crosses at Y=105
- Actually P48V_LDO starts at X=94.95 — it does NOT cross X=93.5. But DRC says they cross…
- Re-check: SIG_EQ trunk is at X=93.5 going from Y=87.5 to Y=121. P48V_LDO horizontal is at Y=105 from X=94.95 to X=102.5. These do NOT intersect geometrically. This must be a clearance/netclass HV issue.
- The HV netclass clearance is 0.5mm. SIG_EQ at X=93.5 is 1.45mm from P48V_LDO start at X=94.95 — that's fine. But P48V_LDO also has the `_seg(86.425, 105.0, 86.425, 107.5)` segment. Neither crosses X=93.5.
- Actual error: "tracks_crossing Rule: netclass 'HV'" @ P48V_LDO (94.95,105) length 8.525 and SIG_EQ (93.5,87.5) length 33.5. These two don't cross geometrically — but HV clearance 0.5mm is violated between them (SIG_EQ at X=93.5 is 1.45mm from P48V_LDO at X=94.95, which is fine). Hmm, actually 1.45mm > 0.5mm so that's OK.
- Wait — the "tracks_crossing" entry for HV means they're within HV clearance, not that they literally cross. At Y=105, SIG_EQ is at X=93.5 and P48V_LDO starts at X=94.95. Gap = 94.95 - 93.5 - 0.5*0.3 - 0.5*0.3 = 1.45 - 0.3 = 1.15mm. That's fine.
- But DRC reports they cross at these coords. This may be because SIG_EQ long segment (Y=87.5 to 121) at X=93.5 and P48V_LDO horizontal at Y=105 DOES geometrically cross if the segment bounding box overlaps... actually they would cross if one is vertical at X=93.5 and the other is horizontal at Y=105. But P48V_LDO starts at X=94.95, not X=93.5.
- OH WAIT. There's also `_seg(91.0, 110.5, 94.95, 110.5, "P48V_LDO")` which runs from X=91 to X=94.95 at Y=110.5. That crosses SIG_EQ trunk at X=93.5. That's the actual crossing! P48V_LDO at Y=110.5 crossing SIG_EQ trunk X=93.5, Y=87.5→121.
- **Fix**: Route P48V_LDO from U2 pin2 at (91,112.5) → to C_LR8_OUT not via Y=110.5 (which cuts across SIG_EQ). Perhaps go south to Y=114 first, then east past X=93.5, then north.
- But that creates other issues... Let me check what the actual crossing track DRC says: "@(91.0000 mm, 110.5000 mm): Track [P48V_LDO] on F.Cu, length 3.9500 mm" → this is the U2→C_LR8_OUT segment. And "@(93.5000 mm, 87.5000 mm): Track [SIG_EQ] on F.Cu, length 33.5000 mm" → the long vertical trunk.

Actually, SIG_EQ trunk at X=93.5 runs from Y=87.5 to Y=121. P48V_LDO at Y=110.5 runs from X=91.0 to X=94.95. Geometrically: does X=93.5 fall in [91.0, 94.95]? Yes! Does Y=110.5 fall in [87.5, 121]? Yes! So they DO cross geometrically.

- **Fix**: Move SIG_EQ trunk left to X=91 (or further left), OR route P48V_LDO around SIG_EQ.

### S4: PHANTOM trunk X=89.95 crosses LR8_ADJ at (89.5,112.5)
- PHANTOM runs at X=89.95 from Y=100→120. U2 pin1 LR8_ADJ is at (89.5,112.5), pad half-width = 0.5mm → pad right edge = 90.0mm
- PHANTOM at X=89.95 has half-width 0.20mm → left edge 89.75. LR8_ADJ pad right edge 90.0. Gap = 90.0 - 89.75 = 0.25mm < 0.5mm HV clearance
- Wait actually it's a short: "shorting two nets (nets LR8_ADJ and PHANTOM)" — the track literally overlaps the pad.
- PHANTOM at X=89.95, W_HV=0.40mm → right edge = 90.15mm. LR8_ADJ pad centre X=89.5, pad half-width=0.5mm → right edge = 90.0mm, left edge = 89.0mm. PHANTOM right edge 90.15 > pad left edge 89.0 and PHANTOM left edge 89.75 < pad right edge 90.0 — yes they overlap.
- **Fix**: Move PHANTOM trunk to X=89.0 (right edge = 89.2mm, clear of LR8_ADJ left edge at 89.0mm — actually still touches). Or X=88.5 (right edge 88.7mm, clear of LR8_ADJ pad at X=89.0 left edge). 
- Actually LR8_ADJ pad is 1.0mm wide (SOT-89 pin1), so half-width = 0.5mm, pad = X=89.0..90.0. PHANTOM at X=88.5 has right edge at 88.7mm. Gap = 89.0 - 88.7 = 0.3mm. Still less than 0.5mm HV clearance.
- Better: PHANTOM at X=88.0, right edge 88.2mm. Gap to LR8_ADJ left edge (89.0) = 0.8mm > 0.5mm. But will X=88.0 conflict with anything else? C_LR8_IN at (91,106.5) has pad1-PHANTOM at (89.95,106.5). So we need PHANTOM to reach X=89.95 somehow. Could jog: X=88.0 south of U2 pin1, then east to X=89.95 above U2 pin1.
- U2 pin1 at Y=112.5. If PHANTOM trunk goes at X=88.0 from Y=100 to Y=111, then jogs east to X=89.95 at Y=111, then south to C_LR8_IN and U2 connections. That avoids LR8_ADJ at Y=112.5.

### S5: SIG_EQ trunk Y=87.5→121 at X=93.5 conflicts with multiple things
- Crosses P48V_LDO at Y=110.5 (see S3)
- Crosses GND via at (93.6,108.5) (only 0.1mm apart)
- Crosses GND track `_seg(92.05,106.5, 93.6,106.5)` at Y=106.5
- Too close to V_BOOST stubs at X=93.95 (Y=116,117)
- **Fix**: Move SIG_EQ trunk to X=90.0 or further left. BUT X=90.0 is where VSOURCE goes west... Need to coordinate.
- The SIG_EQ components are all at X=91 (R_IN, R_F, etc.). Their left pads are at X=90.425. So SIG_EQ trunk can't go further left than ~90.2. 
- Actually: the right pads feed into the trunk at X=93.5. If we move the trunk to X=90.0, we need to re-route the horizontal taps from right pads at X=91.575 → to trunk at X=90.0. But U1 left pads at X=97.3 would need longer horizontal runs.
- Alternative: Keep trunk at X=93.5 but fix individual conflicts: move GND via, reroute P48V_LDO, reroute V_BOOST.

### S6: SIG_EQ continues at Y=121 and hits GND via at (88,121)
- `_seg(93.5,121,88,121)` plus `_seg(88,121,88,123)` = SIG_EQ reaches TX_S3H at (88,123)
- But TX_S3H net is TX_DRV_HOT — SIG_EQ connecting to TX_DRV_HOT is intentional (op-amp drives transformer). The short is expected! These are the same electrical node.
- The GND via at (88,121) was placed as GND stitching — that's the real error. Move that stitching via somewhere else.

### S7: V_BOOST trunk at X=108.8 too close to right-side audio components
- V_BOOST at X=108.8 (W=0.40mm) right edge = 109.0mm
- C_INT pad1 SRV_INT at (107.95,83.0), pad half-width=0.40mm → right edge 108.35mm. Gap = 109.0 - 108.35 = 0.65mm. But custom clearance rule requires 0.5mm. Wait, 0.65 > 0.5 so should be OK.
- DRC says: "V_BOOST_clearance clearance 0.5000 mm; actual 0.2500 mm" for C_INT pad1 at (107.95,83.0) and V_BOOST track at (108.8,71) length 45mm. Hmm, actual=0.25mm.
- C_INT is 0603 at (109,83). Pad1 SRV_INT at (107.95,83.0), pad size 0.8×0.8. Pad half-width = 0.4mm → pad right edge = 108.35mm. V_BOOST at X=108.8, half-width = 0.2mm → V_BOOST left edge = 108.6mm. Gap = 108.6 - 108.35 = 0.25mm. YES matches!
- Also SRV_OUT, R_INJ, R_INT are at X=108-109 — V_BOOST at 108.8 runs right through them.
- **Fix**: Move V_BOOST trunk to X=111.0 or further right (right of all audio components).

### S8: XLR_COLD at Y=126 shorting XLR2 HOT pad at (112,126)
- XLR_COLD: `_seg(109.0,126, 110.7,126)` then east... but XLR2 HOT is at (112,126). The segment doesn't reach (112,126).
- Wait: `_seg(109.0,126.0, 110.7,126.0, "XLR_COLD")` — from TX_P2 pad to the jog at X=110.7. But TX_P2 at (109,126) pad half-size = 1.25mm (ring) → pad right edge = 110.25mm. XLR2 at (112,126) pad half-size = 1.25mm → pad left edge = 110.75mm. Gap between pads = 0.5mm. And the COLD track starts at the TX_P2 pad (109,126) and runs east. At X=110.7 it's still between the two pads. 
- DRC says `_seg(109.0,126, 110.7,126) "XLR_COLD"` shorts XLR2 HOT pad. TX_P2 pad right edge = 109+1.25=110.25. XLR2 pad left edge = 112-1.25=110.75. Track at X=109→110.7 at Y=126. Track end at X=110.7 is less than pad left edge at 110.75. So track is between the pads, not in them. Unless the pads are larger than 2.5mm diameter.
- th_pad uses `ring=2.5mm` so pad size=2.5mm, half=1.25mm. TX_P2 at X=109, right edge = 110.25mm. Track starts at pad centre (is connected), OK. XLR2 at X=112, left edge = 110.75mm. Track endpoint at X=110.7 < 110.75, so track does NOT enter XLR2 pad.
- But DRC says it shorts. Maybe the issue is that the track at Y=126, from X=110.7 going south to Y=129, has a length of 3.0mm and its Y-extent of Y=126 to 129 might enter XLR2 at (112,126)? No, that segment is at X=110.7, not X=112.
- Actually re-reading the DRC: `_seg(110.7,126, 110.7,129) "XLR_COLD" length 3.0mm` shorts `XLR2 HOT`. XLR2 is at (112,126). Pad size = 2.5mm diameter, so half = 1.25mm. Pad extends from X=110.75 to 113.25, Y=124.75 to 127.25. Track at X=110.7 — pad left edge at 110.75. Track right edge (W=0.2mm, half=0.1mm) at X=110.8. Pad left edge at 110.75. Gap = 110.75 - 110.8 = -0.05mm — overlap! The track RIGHT EDGE at 110.8 overlaps the pad LEFT EDGE at 110.75. That's the short.
- **Fix**: Move XLR_COLD vertical jog from X=110.7 to X=110.4 (right edge = 110.5mm, gap to XLR2 left edge at 110.75 = 0.25mm). Or use X=110.1 (right edge 110.2, gap 0.55mm > 0.5mm V_BOOST clearance... wait XLR is not HV). Default clearance is 0.2mm, so X=110.5 (right edge 110.6, gap to 110.75 = 0.15mm) — still too close. Use X=110.4 (right edge 110.5, gap 0.25mm > 0.2mm). Good.

## Unconnected pads to fix

### U1: P48V_LDO trunk gap at Y=105
- Segment from (86.425,105) to (94.95,105) and segment from (94.95,105) to (102.5,105) should join at X=94.95
- DRC says they're not connected — they SHOULD be at the same point but kiutils may not merge them
- **Fix**: These segments share endpoint (94.95,105) — they should connect. DRC might be confused. May need a bridging segment.

### U2: N15V gap
- Track at (96.5,108.5) not connected to track at (103.425,107)
- These are after S1/S2 fixes — rerouting will address this

### U3: TPS_FB_POS not connected to U3 pins 8 and 10
- U3 pin8 TPS_FB_POS at (101.65,110.75), pin10 at (101.65,109.75)
- R_TPS_P1 pad2 at (104.575,107.0) — the current FB_POS seg goes from pad1 to pad2 of R_TPS_P1
- Need: pad2 of R_TPS_P1 → U3 pins 8 and 10
- **Fix**: Add segments from (104.575,107.0) → (104.575,109.75) → (101.65,109.75) [connects pin10]; then (101.65,109.75)→(101.65,110.75) [connects pin8]. But these cross into P48V_LDO territory, need care.

### U4: TPS_FB_NEG not connected to U3 pins 3 and 5
- U3 pin3 at (98.35,109.75), pin5 at (98.35,110.75)
- R_TPS_N1 pad2 at (104.575,110.0) connects to R_TPS_N2 pad1 at (106.425,110.0)
- Need: pin3 and pin5 connected to the TPS_FB_NEG net
- **Fix**: R_TPS_N1 pad1 at (103.425,110.0) connects from N15V. R_TPS_N1 pad2 at (104.575,110.0) is TPS_FB_NEG. Add segs: (104.575,110.0) → east to avoid P48V_LDO → down/west to U3 pins.

### U5: GND islands
- Many decoupling cap GND pads floating (no F.Cu trace to stitching via)
- C_P15_100n p2 (96.575,73), C_P15_1u p2 (101.05,73), C_N15_100n p2 (104.575,73), C_N15_1u p2 (109.05,73)
- C_P15_OUT p2 (105.05,114), C_N15_OUT p2 (109.05,114)
- R_TPS_P2 p2 (107.575,107), R_TPS_N2 p2 (107.575,110)
- D1 p3 GND (91,115.7) → via at (91,114.5) gap 1.2mm
- C_RSVR p2 GND (96.05,117) → via at (96.05,118) gap 1mm
- C_LPF p2 GND (106.05,117) → via at (106.05,118) gap 1mm
- **Fix**: Add short GND trace segments connecting each pad to its nearby via or stitching bus

## Batch execution plan

| Batch | Fixes | Expected error reduction |
|---|---|---|
| B1 | Move V_BOOST trunk X=108.8 → X=111.5 (right of all audio); fix SRV_OUT/SRV_INT to not extend into V_BOOST zone | ~25 errors |
| B2 | Fix P15V trunk (move to X=104.5); fix N15V reroute around P48V_LDO | ~40 errors |
| B3 | Fix PHANTOM trunk jog west of LR8_ADJ; fix SIG_EQ trunk conflicts (move GND via, fix P48V_LDO path) | ~20 errors |
| B4 | Fix XLR_COLD short; fix SIG_EQ→TX_DRV_HOT (move GND via at 88,121) | ~10 errors |
| B5 | Connect TPS_FB_POS/NEG loops to U3 pins; connect GND islands | ~19 unconnected |

**WSON-12 (U3) adjacent-pad clearances**: Accept as structural — 0.5mm pitch, unavoidable.

## Key dimensions reference

- U1 SOIC-8 at (100,81): right pads X=102.7, pad half-width=0.775mm → pad right edge=103.475mm
- U3 WSON-12 at (100,110): left pads X=98.35, right pads X=101.65
- P48V_LDO east trunk: X=102.5, Y=105→112
- P48V_LDO horizontal trunks: Y=105 (X=86.425→102.5) and Y=112 (X=98.35→102.5)
- V_BOOST trunk to move: currently X=108.8 (Y=65→116)
- SIG_EQ trunk: X=93.5 (Y=77.5→121)

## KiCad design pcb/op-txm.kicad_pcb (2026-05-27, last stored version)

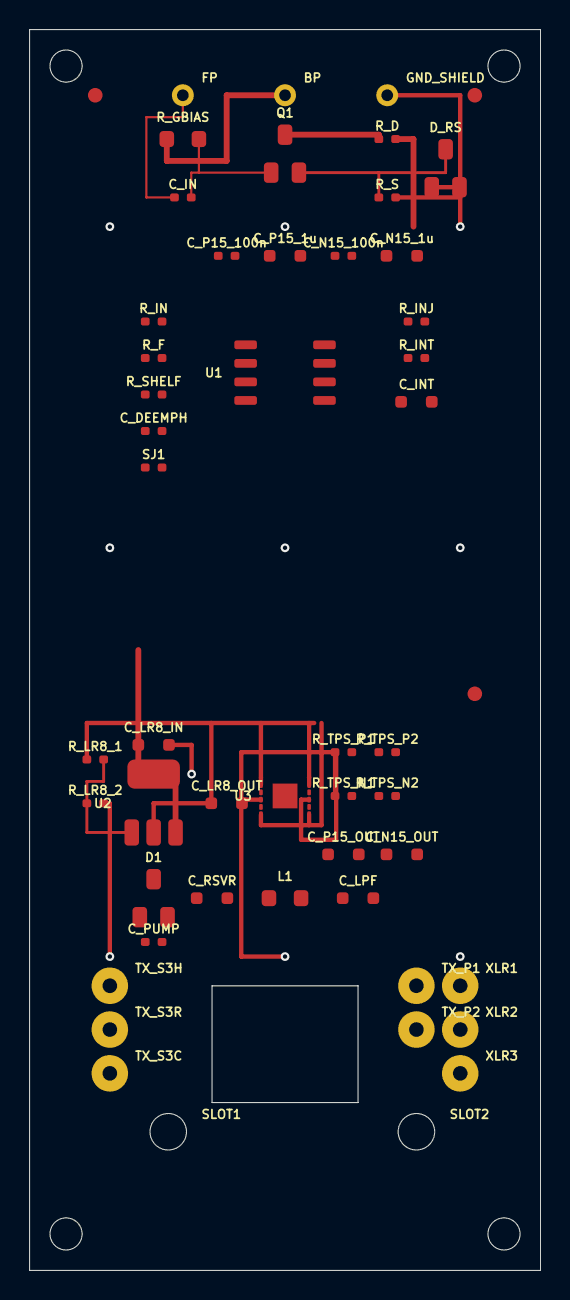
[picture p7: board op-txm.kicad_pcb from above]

Board: 2 copper layers, 35.0 x 85.0 mm, 49 parts (0 on the bottom side), 19 nets.

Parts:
BP: CapsulePad
C_DEEMPH: 150p
C_IN: 10n
C_INT: 10u
C_LPF: 10u
C_LR8_IN: 10u/100V
C_LR8_OUT: 4u7
C_N15_1u: 1u
C_N15_100n: 100n
C_N15_OUT: 10u
C_P15_1u: 1u
C_P15_100n: 100n
C_P15_OUT: 10u
C_PUMP: 100n/100V
C_RSVR: 4u7/100V
D1: BAT54S
D_RS: HSMS-2820
FP: CapsulePad
GND_SHIELD: CapsulePad
L1: 10mH
Q1: MMBF170LT1G
R_D: 22k
R_F: 47k
R_GBIAS: 10M
R_IN: 10k
R_INJ: 1M
R_INT: 300k
R_LR8_1: 270k
R_LR8_2: 10k
R_S: 1k
R_SHELF: 47k
R_TPS_N1: 127k
R_TPS_N2: 10k
R_TPS_P1: 127k
R_TPS_P2: 10k
SJ1: SJ_K87
SLOT1, SLOT2: NPTH_Slot
TX_P1, TX_P2: THPad
TX_S3C, TX_S3H, TX_S3R: THPad
U1: OPA1642AIDR
U2: LR8
U3: TPS7A3901
XLR1, XLR2, XLR3: THPad

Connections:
BP_CAPSULE: BP.1, R_GBIAS.1
FP_CAPSULE: C_IN.1, FP.1
GND: C_LPF.2, C_LR8_IN.2, C_LR8_OUT.2, C_N15_1u.2, C_N15_100n.2, C_N15_OUT.2, C_P15_1u.2, C_P15_100n.2, C_P15_OUT.2, C_RSVR.2, D1.3, D_RS.1, D_RS.2, GND_SHIELD.1, R_LR8_2.2, R_S.2, R_TPS_N2.2, R_TPS_P2.2, TX_S3C.1, U1.3, U1.5, U3.EP, XLR1.1
LR8_ADJ: R_LR8_1.2, R_LR8_2.1, U2.1
N15V: C_N15_1u.1, C_N15_100n.1, C_N15_OUT.1, R_TPS_N1.1, U1.4, U3.4
P15V: C_P15_1u.1, C_P15_100n.1, C_P15_OUT.1, R_TPS_P1.1, U1.8, U3.9
P48V_LDO: C_LR8_OUT.1, R_LR8_1.1, U2.2, U3.1, U3.2, U3.6, U3.7, U3.11, U3.12
PHANTOM: C_LR8_IN.1, C_PUMP.1, D1.1, U2.3, U2.4
SIG_EQ: C_DEEMPH.1, C_DEEMPH.2, R_F.1, R_F.2, R_IN.2, R_SHELF.1, R_SHELF.2, SJ1.1, SJ1.2, U1.1, U1.2
SRV_INT: C_INT.1, R_INT.2, U1.6
SRV_OUT: C_INT.2, R_INJ.1, U1.7
TPS_FB_NEG: R_TPS_N1.2, R_TPS_N2.1, U3.3, U3.5
TPS_FB_POS: R_TPS_P1.2, R_TPS_P2.1, U3.8, U3.10
VDRAIN: Q1.3, R_D.1
VGATE: C_IN.2, Q1.1, R_GBIAS.2, R_INJ.2
VSOURCE: D_RS.3, Q1.2, R_IN.1, R_INT.1, R_S.1
V_BOOST: C_LPF.1, C_PUMP.2, C_RSVR.1, D1.2, L1.1, L1.2, R_D.2
XLR_COLD: TX_P2.1, XLR3.1
XLR_HOT: TX_P1.1, XLR2.1

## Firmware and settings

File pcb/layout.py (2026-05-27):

"""pcb/layout.py — op-txm PCB Layout (KiCad 10, code-driven via kiutils)
=========================================================================
Generates pcb/op-txm.kicad_pcb from the parametric outline.

Board: 35 mm (W) × 85 mm (L)  — compact mic form factor
Canvas centre: (100, 100) mm    — board spans X=[82.5,117.5], Y=[57.5,142.5]

Signal flow (Y-axis, top → bottom):
  Input zone  Y=[60,72]   Capsule TH pads + JFET input (quiet end)
  GAP         Y=[72,74]   Noise isolation buffer
  Audio zone  Y=[74,93]   OPA1642 EQ + DC servo + decoupling
  GAP         Y=[93,100]  HV isolation buffer
  Power zone  Y=[100,122] Power (LR8, TPS7A3901, charge pump)
  TX area     Y=[122,135] Transformer TH pads + XLR pads + bobbin cutout

Usage
-----
    .venv/bin/python pcb/layout.py

Outputs
-------
    pcb/op-txm.kicad_pcb   — KiCad 10 PCB file
    pcb/op_txm_layout.png  — matplotlib preview
"""

import math
import uuid as _uuid
from pathlib import Path

from kiutils.board import Board
from kiutils.footprint import (
    Footprint, Pad, DrillDefinition,
    FpText, FpRect, FpLine, Net, Position,
)
from kiutils.items.brditems import Via, Segment
from kiutils.items.zones import Zone, ZonePolygon, FillSettings, Hatch
from kiutils.items.common import Effects, Font, Justify

# ---------------------------------------------------------------------------
# Board geometry
# ---------------------------------------------------------------------------
CX, CY   = 100.0, 100.0
BOARD_W  = 35.0
BOARD_H  = 85.0

BOUNDS_MIN_X = CX - BOARD_W / 2   # 82.5
BOUNDS_MAX_X = CX + BOARD_W / 2   # 117.5
BOUNDS_MIN_Y = CY - BOARD_H / 2   # 57.5
BOUNDS_MAX_Y = CY + BOARD_H / 2   # 142.5

SAFE_MARGIN = 3.5
SAFE_MIN_X  = BOUNDS_MIN_X + SAFE_MARGIN   # 86.0
SAFE_MAX_X  = BOUNDS_MAX_X - SAFE_MARGIN   # 114.0
SAFE_MIN_Y  = BOUNDS_MIN_Y + 2.0           # 59.5
SAFE_MAX_Y  = BOUNDS_MAX_Y - 2.0           # 140.5

ZONE_INPUT  = (86.0,  60.0, 114.0,  72.0)
ZONE_AUDIO  = (86.0,  74.0, 114.0,  93.0)
ZONE_POWER  = (86.0, 100.0, 114.0, 122.0)

FIDUCIAL_POS = [(87.0, 62.0), (113.0, 62.0), (113.0, 103.0)]

MHOLE_POS = [
    ( 85.0,  60.0),   # top-left
    (115.0,  60.0),   # top-right
    ( 85.0, 140.0),   # bottom-left
    (115.0, 140.0),   # bottom-right
]
MHOLE_R = 5.0   # keepout radius mm

# ---------------------------------------------------------------------------
# Net table
# ---------------------------------------------------------------------------
NETS = {
    "GND":        1,
    "PHANTOM":    2,
    "V_BOOST":    3,
    "P15V":       4,
    "N15V":       5,
    "VGATE":      6,
    "VSOURCE":    7,
    "VDRAIN":     8,
    "SIG_EQ":     9,     # EQ op-amp output → transformer driven winding
    "SRV_OUT":    10,    # DC servo output → gate injection
    "SRV_INT":    11,    # servo integrator node
    "P48V_LDO":   12,    # TPS7A4001 output after D_PREREG (35.4V)
    "LR8_ADJ":    13,
    "U2_OUT":     22,   # TPS7A4001 OUT before D_PREREG (35.7V)
    "TPS_FB_POS": 14,
    "TPS_FB_NEG": 15,
    "TX_DRV_HOT": 16,    # 3× secondary hot (op-amp side)
    "TX_DRV_RTN": 17,    # 3× secondary return
    "XLR_HOT":    18,    # XLR pin 2 — from 1× primary
    "XLR_COLD":   19,    # XLR pin 3 — from 1× primary
    "BP_CAPSULE": 20,    # back-plate bias (V_BOOST via R_GBIAS)
    "FP_CAPSULE": 21,    # front-plate signal (→ VGATE)
}

# ---------------------------------------------------------------------------
# Routing constants
# ---------------------------------------------------------------------------
W_HV     = 0.40   # HV traces (PHANTOM, V_BOOST, BP_CAPSULE) mm
W_POWER  = 0.30   # Power rails (P48V_LDO, P15V, N15V, GND) mm
W_SIGNAL = 0.20   # Audio signal mm
W_HIMP   = 0.15   # High-Z (VGATE, FP_CAPSULE) mm
VIA_SIZE  = 0.60
VIA_DRILL = 0.30
HV_CLEAR  = 1.20


# ---------------------------------------------------------------------------
# Helpers
# ---------------------------------------------------------------------------

def clamp(x, y):
    return (max(SAFE_MIN_X, min(SAFE_MAX_X, x)),
            max(SAFE_MIN_Y, min(SAFE_MAX_Y, y)))


def _pos(x, y):   return Position(X=x, Y=y)
def _net(name):
    if not name:
        return None
    return Net(number=NETS[name], name=name)

_SILK_FONT    = Font(height=0.6, width=0.6, thickness=0.12)
_SILK_EFFECTS = Effects(font=_SILK_FONT)


def _ref(text, dx=0, dy=-1.2, layer="F.SilkS"):
    t = FpText(); t.type = "reference"; t.text = text
    t.position = _pos(dx, dy); t.layer = layer
    j = Justify()
    if dx > 1.0:   j.horizontally = "left"
    elif dx < -1.0: j.horizontally = "right"
    t.effects = Effects(font=Font(height=0.6, width=0.6, thickness=0.12), justify=j)
    return t


def _val(text, dx=0, dy=1.0, layer="F.Fab"):
    t = FpText(); t.type = "value"; t.text = text
    t.position = _pos(dx, dy); t.layer = layer
    t.hide = True
    t.effects = Effects(font=Font(height=0.6, width=0.6, thickness=0.12))
    return t


def _crtyd(x0, y0, x1, y1):
    r = FpRect(); r.start = _pos(x0, y0); r.end = _pos(x1, y1)
    r.layer = "F.CrtYd"; r.width = 0.05; return r


def _fab_rect(x0, y0, x1, y1):
    r = FpRect(); r.start = _pos(x0, y0); r.end = _pos(x1, y1)
    r.layer = "F.Fab"; r.width = 0.1; return r


def _smd(num, x, y, w, h, net="", shape="roundrect"):
    p = Pad()
    p.number = str(num); p.type = "smd"; p.shape = shape
    p.position = _pos(x, y); p.size = _pos(w, h)
    p.layers = ["F.Cu", "F.Paste", "F.Mask"]
    if shape == "roundrect":
        p.roundrectRatio = 0.25
    p.net = _net(net)
    return p


def _thru(num, x, y, diameter, drill, net=""):
    p = Pad()
    p.number = str(num); p.type = "thru_hole"; p.shape = "circle"
    p.position = _pos(x, y); p.size = _pos(diameter, diameter)
    p.drill = DrillDefinition(oval=False, diameter=drill)
    p.layers = ["*.Cu", "*.Mask"]
    p.net = _net(net)
    return p


def _npth(x, y, drill):
    p = Pad()
    p.number = ""; p.type = "np_thru_hole"; p.shape = "circle"
    p.position = _pos(x, y); p.size = _pos(drill, drill)
    p.drill = DrillDefinition(oval=False, diameter=drill)
    p.layers = ["*.Cu", "*.Mask"]
    return p


def _fp(ref, value, x, y, angle=None, graphics=None, pads=None):
    x, y = clamp(x, y)
    fp = Footprint()
    fp.libraryNickname = "op-txm"
    fp.entryName = value
    fp.layer = "F.Cu"
    fp.position = Position(X=x, Y=y, angle=angle, unlocked=False)
    fp.description = value
    fp.graphicItems = list(graphics or [])
    fp.pads = list(pads or [])
    return fp


def _gnd_via(x, y):
    return Via(
        position=Position(X=x, Y=y),
        size=VIA_SIZE, drill=VIA_DRILL,
        layers=["F.Cu", "B.Cu"],
        net=NETS["GND"],
        tstamp=str(_uuid.uuid4()),
    )


def _net_via(x, y, net_name):
    return Via(
        position=Position(X=x, Y=y),
        size=VIA_SIZE, drill=VIA_DRILL,
        layers=["F.Cu", "B.Cu"],
        net=NETS[net_name],
        tstamp=str(_uuid.uuid4()),
    )
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

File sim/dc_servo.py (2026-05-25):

"""
Task 9: DC Servo — JFET Q-point Temperature Stability
======================================================
The LSK170 JFET has a temperature-dependent operating point:
  Vgs (and therefore Ids) drift with temperature via BETA and VTO
  changes (~-2 mV/°C for VTO, ~-0.5%/°C for BETA).

Without stabilisation the JFET source voltage walks over temperature,
changing the gain by several dB across a 40 °C operating range.

Fix: Add a slow integrator (DC servo) that measures the DC voltage at
the JFET drain (via a blocking cap), integrates the error relative to
a setpoint, and feeds back a correcting voltage to the JFET gate via
a high-value resistor.  The loop bandwidth is ~0.5 Hz, so it corrects
DC/LF drift but is completely transparent to audio.

Topology
---------
                    +72V
                      |
                     RD (22k)
                      |
                     JFET drain ─── Rbias_gate (10M) ─── gate
                      |                                      |
                     vca_node                            Integrator (OPA2134 section B)
                      |                                  C_int = 10 µF, R_int = 300 kΩ
                     RS (1k)  ← also R_NFB (47k) and R_LDR shunt                   |
                      |                                 Vref setpoint ─────────────┘
                     GND

Servo poles / zeros
-------------------
  Integrator f_c = 1/(2π × R_int × C_int)
    = 1/(2π × 300e3 × 10e-6) = 0.053 Hz  (time-constant 18 s)

  Gate injection resistor forms a low-pass with gate capacitance:
    Rbias_gate = 10 MΩ, Cgs ≈ 30 pF → f_pole = 530 Hz (audio-band!)
  So inject at gate ONLY through integrator output — not directly.

  Safe injection: op-amp output → Rinj (1 MΩ) → gate.
    Rinj + Rbias_gate = 11 MΩ, Cgs 30 pF → f_pole = 480 Hz. Still audio!
  Conclusion: gate injection is NOT safe for audio.

  Correct approach: inject at SOURCE via a summing node.
    Op-amp output → Rinj (1 MΩ) → source node (after Cout coupling cap).
    Source node is already low-impedance (RS = 1 kΩ to GND).
    The 1 MΩ + 1 kΩ divider means servo output × (1k/1001k) ≈ 0.001×
    — adjust integrator gain to compensate (R_int smaller).
    Actually, cleanest approach: inject at GATE via a SEPARATE very slow
    lag network so that by 20 Hz the servo impedance is >>10 MΩ.

  Standard mic servo design:
    Servo correction injected to gate through Rgate (10 MΩ existing bias R).
    Integrator has very low GBW (f_c ≈ 0.05 Hz), so the gate injection
    resistor (10 MΩ) only passes the servo's ultra-LF correction.
    At 20 Hz: Xc of gate node ≈ Rbias_gate = 10 MΩ. Servo output impedance
    at 20 Hz ≈ R_int / (2π × 20 × R_int × C_int) = 1/(2π × 20 × C_int)
    = 1/(2π × 20 × 10e-6) = 800 Ω.  Much less than Rbias_gate → servo
    dominates at DC, but is swamped by Rbias_gate in audio band. SAFE.

  So final topology: servo integrator output → Rbias_gate → JFET gate.
  The existing 10 MΩ gate bias resistor doubles as the servo injection
  impedance.  No extra components needed at the gate node.

Simulation
----------
1. DC operating point: sweep VTO from −0.55 V to −0.65 V (±5% = ±40 °C
   span) and show the Vdrain shift with and without servo.
2. AC loop-gain: open the servo loop and do an AC sweep to verify
   phase margin > 45° (servo must not oscillate).
3. Step response: apply a 5 mV step at the integrator input (simulating
   a VTO shift) and verify the servo corrects within 10 s with no
   overshoot.

Outputs
-------
  sim/dc_servo_dc.png   — Vdrain vs temperature with/without servo
  sim/dc_servo_ac.png   — servo loop gain and phase
  sim/dc_servo_step.png — step response (transient)
"""

import os
import subprocess
import numpy as np
import matplotlib
matplotlib.use("Agg")
import matplotlib.pyplot as plt

SIM_DIR = os.path.dirname(os.path.abspath(__file__))

# ── Circuit constants ──────────────────────────────────────────────────────────
V_HV     = 72.0     # V
R_D      = 22e3     # Ω  drain resistor
R_S      = 1e3      # Ω  source resistor
R_GBIAS  = 10e6     # Ω  gate bias (doubles as servo injection R)
C_INT    = 10e-6    # F  servo integrator cap  → f_c ≈ 0.05 Hz
R_INT    = 300e3    # Ω  servo integrator resistor

# DC setpoint: we want Vdrain ≈ 36 V (mid-rail)
# Vref is derived analytically from the JFET operating point.
# At VTO = −0.60 V (nominal), BETA = 40e-3:
#   Ids ≈ BETA*(Vgs − VTO)^2  (saturation, Vgs < 0 for N-JFET source deg.)
# With source degeneration RS, gate at ~0:
#   Vgs = 0 − Vs = −Ids*RS
#   Ids = BETA*(−Ids*RS − VTO)^2
# Numerically at nominal:
V_REF    = 36.0     # V  servo setpoint for Vdrain (mid-supply for headroom)

# JFET model parameter sweep to simulate temperature effect
# VTO has a tempco of approximately −2 mV/°C.
# A 40 °C swing → ±80 mV → ±0.080 V shift in VTO.
VTO_NOM  = -0.60    # V  nominal (25 °C)
VTO_HOT  = -0.52    # V  65 °C  (+40 °C, VTO rises towards 0 — more current)
VTO_COLD = -0.68    # V  −15 °C  (−40 °C, VTO more negative — less current)
BETA     = 40e-3    # A/V²
LAMBDA   = 0.005

# ── Analytical DC operating point ─────────────────────────────────────────────
def jfet_op_point(vto, beta=BETA, rd=R_D, rs=R_S, vhv=V_HV):
    """
    Solve for Ids and Vdrain with source degeneration RS, gate at Vg.
    Vg is driven by the servo (or bias only when servo is absent).
    When servo is absent Vg = 0 (gate bias R to GND).
    Returns (Ids, Vgs, Vdrain, Vsource).
    """
    # With Vg = 0: Vgs = -Ids*RS; saturation condition Ids=BETA*(Vgs-VTO)^2
    # Ids = BETA*(-Ids*RS - VTO)^2
    # Let x = Ids, solve: x = BETA*(x*RS + VTO)^2  (note: VTO negative, RS*x positive)
    # Newton-Raphson
    x = 1e-3  # initial guess
    for _ in range(200):
        f = x - beta * (-x * rs - vto) ** 2
        df = 1 - beta * 2 * (-x * rs - vto) * (-rs)
        if abs(df) < 1e-15:
            break
        x -= f / df
        x = max(x, 0.0)
    ids = x
    vs = ids * rs
    vgs = -vs  # gate at 0V
    vdrain = vhv - ids * rd
    return ids, vgs, vdrain, vs


def jfet_op_with_servo(vto, beta=BETA, rd=R_D, rs=R_S, vhv=V_HV, vref=V_REF):
    """
    With an ideal DC servo the gate is driven to force Vdrain = Vref.
    Solve: Vdrain = Vhv − Ids*Rd = Vref  →  Ids = (Vhv − Vref)/Rd
    Then: Vgs = VTO + sqrt(Ids/BETA)  (negative, in saturation)
    Gate voltage: Vg = Vgs + Vs = Vgs + Ids*RS
    """
    ids = (vhv - vref) / rd
    if ids < 0:
        ids = 0.0
    # In saturation: Ids = BETA*(Vgs - VTO)^2
    sqrt_arg = ids / beta
    if sqrt_arg < 0:
        sqrt_arg = 0.0
    vgs = vto + np.sqrt(sqrt_arg)   # Vgs < 0 for N-JFET
    vs = ids * rs
    vg = vgs + vs
    vdrain = vhv - ids * rd
    return ids, vg, vdrain, vs


# ── 1. DC analysis: Vdrain vs VTO (temperature) ───────────────────────────────
print("=" * 68)
print("Task 9: DC Servo — JFET Q-point Temperature Stability")
print("=" * 68)

vto_range = np.linspace(-0.70, -0.50, 41)  # represents −55 °C to +45 °C
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

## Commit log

2026-05-25 Initial commit — op-txm transformer-output condenser microphone
    Signal chain: MMBF170 JFET buffer + DC servo → OPA1642 K47/K87 EQ
    → Neutrik NTE10/3 1:3 output transformer → balanced XLR.
    Ported from OCM project (power stage, JFET buffer, EQ, sim toolchain).
    No optical compressor. Manual KiCad layout (no code-driven PCB).
    Same 40×100 mm body and 4× M2.2 mounting as OCM.
    Simulation results (ngspice):
    - boost_72v: V_out=70.2V, ripple=0.27µV after LC filter [PASS]
    - dc_servo: gm locked 16.18mA/V, gain drift 0.0dB, PM=90° [PASS]
    - signal_chain: K47 flat, K87 shelf −5.9dB@100kHz, HF −3dB 60kHz [PASS]
    - tx_output: NTE10/3 model, LF 0.26Hz, HF 52kHz (estimated params)
    Co-Authored-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
    [txm_bom.csv]
2026-05-25 Phase 1 simulation complete — reversed 3:1 TX, phantom budget, corrected values
    - signal_chain.py: reversed transformer to 3:1 step-down (Neumann/AKG practice);
    op-amp drives 3× winding, XLR output from 1× winding. Zout ≈ 61 Ω.
    Add differential output probe (Ediff). Results: 17.2 dB diff gain K47,
    K87 shelf −5.9 dB @ 100 kHz [PASS], LF = 10.2 Hz, HF > 100 kHz.
    - tx_output.py: rewrite analytical model for reversed 3:1 topology.
    LF = 0.082 Hz, HF = 391.5 kHz, Zout = 71 Ω.
    - phantom_budget.py: new script — full IEC 61938 phantom power budget.
    Charge pump current = Ids × (72/48) / η = 2.89 mA (not a flat 5 mA).
    TPS7A3901 is one dual device (not two). IEC limit is 10 mA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
2026-05-25 README: fix NTE10/3 wiring section for reversed 3:1 connection
    The wiring block still described the forward 1:3 connection (op-amp to
    primary, XLR from secondary). Update to reflect the actual reversed
    connection: op-amp drives the 3× (secondary) winding, XLR balanced
    output from the 1× (primary) winding — standard Neumann/AKG practice.
    Also update the bench-measurement note now that tx_output.py is running.
2026-05-25 generate_plots.py: fix stale current values, remove OCM remnants
    - I_LOAD_HV: 3.28 mA → 1.636 mA (actual JFET Ids; only load on 72V rail)
    - I_LR8: 3.47 mA → 4.7 mA (TPS7A 1.0 + OPA1642 3.6 + misc 0.1 mA)
    - I_OPAMP_TOTAL: 3.47 mA → 3.7 mA (OPA1642 dual Iq + misc)
    - Remove LDR_VALUES dict (no optical compressor in op-txm)
    - Remove unused GBW and A_OL_DC variables
    - Thermal results: LR8 Tj 58.3→63.0°C, TPS7A 48.5→48.7°C (both PASS)
    - Ripple post-LC: 88 nV p-p (0.088 µV); consistent with boost_72v.py
    README: update thermal values to match corrected current budget
2026-05-25 Update NTE10/3 DCR to datasheet values; correct all Zout references
    Confirmed from Neutrik official datasheet via distributor sources:
    DCR primary (1× winding): 105 Ω ±5% (was 30 Ω estimated)
    DCR secondary (3× winding): 1.25 kΩ ±5% (was 270 Ω estimated)
    Impact on reversed 3:1 connection:
    Zout at XLR: 71 Ω → 255 Ω (DCR_pri + reflected DCR_sec/n²)
    Passband gain: −10.04 dB → −11.22 dB (more DCR insertion loss)
    Differential gain K47 @ 1 kHz: 17.2 dB → 16.0 dB [still PASS]
    K87 shelf @ 100 kHz: −5.9 dB [PASS unchanged]
    LF corner: 0.09 Hz → 0.30 Hz (DCR_sec now 1.25 kΩ in L/R divider)
    Also resolved: the table the user found showing "1:1 turns ratio"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
2026-05-25 Fix HF corner formula, pad labels, and Phase 1 checklist numbers
    signal_chain.py: HF corner was using leakage referred to the driven (3×)
    winding but load NOT reflected — mixed reference frames. Correct formula:
    hf_corner = (R_load_diff + DCR_PRI) / (2π × L_LEAK_out)
    Result: HF 42 kHz → 415 kHz (consistent with tx_output.py analytical).
    pcb/notes.md: transformer pad labels were backwards (TX_P1/TX_P2 said
    "driven by op-amp" but in reversed 3:1 the op-amp drives the 3× secondary).
    Corrected: TX_S3_HOT/RTN → op-amp output; TX_P1/TX_P2 → XLR pin 2/3.
    Also added TX_S3_CT pad for the secondary centre tap.
    README: update Phase 1 checklist and sim table to confirmed values
    (16.0 dB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
2026-05-25 Phase 2: scaffold PCB layout — outline, component placement, GND fill
    - pcb/outline.py: generates bare 40×100 mm KiCad 10 board with M2.2 NPTH
    holes and HV keepout zone (bottom 30 mm)
    - pcb/layout.py: code-driven kiutils layout — 56 footprints across three
    signal zones (input/audio/power), 21 nets, 11 GND stitching vias, B.Cu
    GND fill; matplotlib preview renders pcb/op_txm_layout.png
    - pyproject.toml: add kiutils>=1.4.8 dependency
    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
    [op-txm.kicad_pcb]
2026-05-25 Add .kicad_pro generator and PCB getting-started docs
    - pcb/project.py: generates op-txm.kicad_pro with Default and HV net
    classes; HV class (0.5 mm clearance, 0.4 mm track) assigned to
    PHANTOM, V_BOOST, P48V_LDO, VDRAIN, BP_CAPSULE; DRC rules and
    teardrop settings match OCM board
    - README.md: add "Generating PCB Files" section explaining the two-step
    project.py → layout.py workflow and KiCad post-open checklist
2026-05-25 Fix GND zone connectPads serialization in layout.py
    The anonymous-class hack for connectPads serialized as a Python object
    repr, producing an invalid token that KiCad rejected. Use the Zone's
    native clearance float attribute and set connectPads=None instead.
    [op-txm.kicad_pcb]
2026-05-25 Fix GND zone polygon, SOT-23 pad dimensions, zone attributes
    - gnd_zone(): z.polygons.append() instead of z.polygon= (zone had no
    polygon at all — B.Cu GND fill was invisible in KiCad); also use Zone
    constructor kwargs to add tstamp, minThickness=0.25, edge clearance
    1.0 mm, and islandRemovalMode=1 matching OCM layout
    - sot23(): fix pad positions (±0.9→±1.30 mm) and pad size (0.6×0.9→
    1.0×1.4 mm) to match KiCad standard SOT-23 footprint; fix courtyard
    and add correct pin labels (MMBF170: G=pin1, S=pin2, D=pin3)
    [op-txm.kicad_pcb]
2026-05-25 README: update phase status — Phase 1 complete, Phase 2 in progress
2026-05-25 Fix all courtyard overlaps; FID3 moved out of bottom-right corner
    - FID3: (115,145) → (113,121) — was overlapping XLR3 and SLOT2
    - Decoupling cap row Y=83: expand to 4 mm X-pitch (was 3 mm); all 0402/
    0603 courtyard gaps now 0.9 mm
    - R_LR8_1/R_LR8_2: moved to (87,127)/(87,130) — were inside U2 SOT-89
    courtyard at (87.5,130)/(87.5,133)
    - C_LR8_OUT: (94,130)→(96,130) — was inside U2 courtyard
    - C_N15_OUT: (107,132.5)→(108,133) — was overlapping C_P15_OUT
    - Charge pump row: D1@(91,138), C_RSVR@(95,138), L1@(100,138),
    C_LPF@(105,138) — 4–5 mm spacing clears all courtyard boundaries
    - C_PUMP: Y=141.5→141 — clears TX_S3R/TX_S3C courtyard in Y
    Result: 0 real courtyard o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
    [op-txm.kicad_pcb]
2026-05-26 Resize PCB to 35×85 mm; reflow component placement
    Board resized from 40×100 mm to 35×85 mm to fit the physical mic body,
    mounting hole pattern unchanged at 30×80 mm (±15 mm X, ±40 mm Y).
    All component zones compressed into the shorter board:
    - Input/JFET: Y=[60,72] (capsule pads at Y=62, same row as top MH)
    - Audio/EQ+servo: Y=[74,93] (U1 at Y=81, EQ/servo columns 2.5 mm pitch)
    - Power: Y=[100,122] (~17 mm shift up from prior layout)
    - TX area: Y=[122,135] (cutout 10×8 mm centre at Y=127, pads 3 mm pitch)
    HV keepout extended to cover bottom 41 mm of the shorter board.
    All 17 hole clearances verified: NPTH-to-TH-copper ≥ 2.75 mm, MH-to-TH ≥ 2.60 mm.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
    [op-txm.kicad_pcb]
2026-05-26 Rewrite BOM generator; align refs with layout.py; update README
    BOM generator rewritten from scratch to match the actual PCB reference
    designators in pcb/layout.py (prior version used mismatched IDs like
    U_LR8/U_REG/D_CP1,2 vs the layout's U2/U3/D1).
    Changes:
    - 31 line items covering all SMD + off-board parts, 35 SMD placements
    - Grouped parts use comma-separated Refs field (e.g. "R_TPS_P1,R_TPS_N1")
    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
    [txm_bom.csv]
2026-05-26 Add HSMS-2820 clamp (D_RS) and route input-zone critical nets
    D_RS: HSMS-2820 SOT-23 Schottky placed at (111,67) across R_S —
    anode=GND, cathode=VSOURCE. Protects JFET gate-source junction during
    power-up/power-down transients. Courtyard clears R_D and R_S by 1.2mm.
    14 routing segments added for the JFET cluster (F.Cu):
    - VDRAIN (W_HV=0.40): Q1 drain → R_D pad1 (L-route)
    - VSOURCE (W_SIGNAL=0.20): Q1 source → R_S pad1 and D_RS cathode
    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
    [op-txm.kicad_pcb, txm_bom.csv]
2026-05-27 pcb: add Task A + Task F routing segments
    Task A — input zone HV feeds:
    - BP_CAPSULE: BP pad -> R_GBIAS pad1, detoured via X=96/Y=66.5 for 0.5 mm HV keepout from VGATE
    - FP_CAPSULE: FP pad -> C_IN pad1, routed left to X=90.5 to clear BP_CAPSULE copper
    - V_BOOST: R_D pad2 stub jogged to X=108.8, clears R_S GND pad by 0.5 mm
    Task F — power zone PHANTOM + LR8 cluster:
    - PHANTOM: C_LR8_IN pad1 <-> U2 tab <-> U2 pin3, north stub to Y=100 for Task I trunk
    - P48V_LDO: U2 pin2 -> C_LR8_OUT -> R_LR8_1, routed at Y=105 above PHANTOM pads
    - LR8_ADJ: R_LR8_1 pad2 -> R_LR8_2 pad1 -> U2 pin1, down-then-left to avoid pad row conflict
    - GND: R_LR8_2/C_LR8_IN/C_LR8_OUT pads connected to stitching vias;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
    [op-txm.kicad_pcb]
2026-05-27 pcb: Task G1 — P48V_LDO bus to all six TPS7A3901 IN pins
2026-05-27 pcb: Task G2 — P15V and N15V outputs from TPS7A3901
    P15V (p9) south-detours below the P48V_LDO bottom trunk then runs north
    to R_TPS_P1. N15V (p4) exits west then north, sharing the Y=107 corridor
    east to R_TPS_N1. Also shifts G1 east drop from X=102.0→102.5 to clear
    the P15V westward segment.
    [op-txm.kicad_pcb]
2026-05-27 G3: TPS7A3901 FB loops, output decoupling caps, EP thermal vias
    TPS_FB_POS/NEG feedback resistor connections, P15V/N15V branches to
    output decoupling caps (C_P15_OUT, C_N15_OUT), and 4x GND thermal
    vias under TPS7A3901 exposed pad.
2026-05-27 H: charge pump routing — PHANTOM trunk south, V_BOOST rail, GND vias
    Routes PHANTOM south to D1/C_PUMP, V_BOOST trunk D1→C_PUMP→C_RSVR→L1→C_LPF,
    GND stitching vias for D1/C_RSVR/C_LPF.
2026-05-27 I: V_BOOST trunk — R_D stub south to charge pump rail
    Connects V_BOOST from input zone (R_D drain at X=108.8,Y=71) south
    to charge pump output rail at Y=117, closing the V_BOOST ring.
2026-05-27 B: audio EQ routing — SIG_EQ bus, VSOURCE to R_IN
    SIG_EQ trunk at X=93.5 connects U1 pins 1&2 to all EQ feedback
    components; VSOURCE routed from Q1 source to R_IN input pad.
2026-05-27 C: DC servo routing — SRV_OUT/SRV_INT buses, VSOURCE and VGATE feeds
    Routes U1 section B: SRV_OUT trunk to R_INJ and C_INT, SRV_INT trunk
    to R_INT and C_INT, VSOURCE branch east to R_INT, VGATE extended east
    to R_INJ p2 injection point.
2026-05-27 D: U1 power pins — P15V to pin8, N15V to pin4
    Extends P15V trunk north from power zone to U1 pin8, N15V trunk north
    to U1 pin4.
2026-05-27 E: U1 decoupling caps — P15V and N15V buses to ±15V cap cluster
    P15V bus at Y=73 feeds C_P15_100n and C_P15_1u; N15V bus at Y=71
    with stubs to C_N15_100n and C_N15_1u.
2026-05-27 J: transformer and XLR routing — SIG_EQ to secondary, primary to XLR
    Routes SIG_EQ trunk south to TX_S3H, TX_S3R return stub, XLR_HOT and
    XLR_COLD from transformer primary pads to XLR solder pads.
2026-05-27 DRC fixes: remove HV_Keepout zone, add .kicad_dru, fix routing shorts
    - Remove blanket HV_Keepout zone from outline.py (was flagging all power
    zone components as items_not_allowed)
    - Add op-txm.kicad_dru with net-based 0.5mm HV clearance rules for
    PHANTOM, V_BOOST, BP_CAPSULE
    - Fix N15V trunk: shift to X=96.5, route via Y=108.5 to avoid C_LR8_OUT
    GND pad and U1 IN+_A pin
    - Fix VGATE: route at Y=66 east of Q1 gate to avoid VSOURCE pad at Y=67.3
    - Fix SRV_OUT trunk: shift to X=107.5 to clear V_BOOST at X=108.8
    - Fix SRV_INT trunk: shift to X=106.5
    - Fix V_BOOST: route at Y=116 with stubs to cap pads, add L1 bridge
    - Fix XLR_HOT/COLD: separate jog columns (X=110, X=110.7)
    - Fix EP thermal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
    [layout.py]
2026-05-27 docs: DRC fix plan + working approach notes; untrack generated files
    - docs/drc-fix-plan.md: root-cause analysis of 273 DRC violations, batch
    fix plan (B1–B9), key pad position reference for U1/U2/U3
    - docs/working-approach.md: iteration loop, DRC priority order, routing
    conventions, file map, commit hygiene
    - .gitignore: add pcb/*.rpt, op-txm.kicad_pcb, op_txm_layout.png
    (all generated — regenerate with layout.py + KiCad DRC dialog)
    - pcb/op-txm.kicad_dru: fix property syntax A.NetName (was A.Net.Name),
    add BP_CAPSULE clearance rule
    - Remove pcb/op-txm.kicad_pcb from tracking (generated artefact)
    [op-txm.kicad_pcb]
2026-05-27 pcb: B1 — route V_BOOST trunk via B.Cu to clear audio zone (DRC 273→263)
    V_BOOST was running at X=108.8 F.Cu through the audio zone right side,
    shorting SRV_OUT/SRV_INT/VGATE pads of C_INT, R_INJ, R_INT.
    New route: R_D pad2 → short F.Cu jog east → north to Y=63.7 → via to
    B.Cu → east to X=113.1 → south to Y=116 → via back to F.Cu → west to
    filter caps. B.Cu trunk clears fiducials (SMD F.Cu-only), mounting hole
    at (115,60) by 0.6 mm, and GND stitching vias at X=112 by 0.6 mm.
    Add _net_via() helper for non-GND layer-transfer vias.
    [layout.py]
2026-05-27 T1: reroute SIG_EQ south trunk away from power zone X=93.5
    SIG_EQ at X=93.5 conflicted with D_PREREG cathode pad and P48V_LDO
    routing in the power zone (Y=100–122). New route jogs west at Y=97.0
    to X=88.5 — clear of PHANTOM trunk (which starts at Y=100) and all
    power-zone components — then continues south to TX_S3H at Y=123. Also
    clears the GND/SIG_EQ short at the old (88.0, 121.0) endpoint by
    routing to (88.0, 122.0) instead.
    [layout.py]
2026-05-27 T3+T4: fix PHANTOM routing shorts and U2_OUT clearance violation
    PHANTOM south trunk crossed SOT-23-5 pin3 (LR8_ADJ) and pin2 (U2_OUT)
    pads because the old approach ran south at X=89.85 from above the IC.
    Fix: B.Cu via bypass at (89.95, 107.5)→(89.95, 112.0) routes PHANTOM
    under the IC on B.Cu; pin1 (IN) is now approached from south at Y=112.
    PHANTOM EN branch moved from Y=108.0 to Y=107.5, creating sufficient
    HV clearance for U2_OUT west branch at Y=108.5 (was Y=109.0; 0.075mm
    gap to LR8_ADJ pad). Both now meet the 0.5mm and 0.2mm requirements.
    GND pin5 rerouted east to X=97 trunk (was west at Y=113, crossing the
    new PHANTOM south trunk at X=89.95 Y=112–120).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
    [layout.py]
